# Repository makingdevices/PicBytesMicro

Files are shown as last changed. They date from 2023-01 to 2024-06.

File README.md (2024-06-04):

<!-- Improved compatibility of back to top link: See: https://github.com/othneildrew/Best-README-Template/pull/73 -->

<!--
*** Thanks for checking out the Best-README-Template. If you have a suggestion
*** that would make this better, please fork the repo and create a pull request
*** or simply open an issue with the tag "enhancement".
*** Don't forget to give the project a star!
*** Thanks again! Now go create something AMAZING! :D
-->

<!-- PROJECT SHIELDS -->
<!--
*** I'm using markdown "reference style" links for readability.
*** Reference links are enclosed in brackets [ ] instead of parentheses ( ).
*** See the bottom of this document for the declaration of the reference variables
*** for contributors-url, forks-url, etc. This is an optional, concise syntax you may use.
*** https://www.markdownguide.org/basic-syntax/#reference-style-links
-->
[][ig-url]
[][sponsor-url]
[][stars-url]
[][issues-url]
[][linkedin-url]

<!-- PROJECT LOGO -->
<br />
<div align="center">
  <a href="https://makingdevices.com/links/">
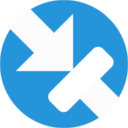
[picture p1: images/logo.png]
    
  </a>

<h3 align="center">Making Devices</h3>

  <p align="center">
    Open Source projects where we struggle with engineering, electronics, coding and who knows what else... Pic Bytes Micro is a 8-bit console based in the PIC18F4550 with an analog LED matrix as the screen.
  </p>
</div>

<!-- TABLE OF CONTENTS -->
<details>
  <summary>Table of Contents</summary>
  <ol>
    <li>
      <a href="#about-the-project">About The Project</a>
      <ul>
        <li><a href="#built-with">Built With</a></li>
      </ul>
    </li>
    <li>
      <a href="#Build-one">Build one</a>
      <ul>
      </ul>
    </li>
    <li><a href="#usage">Usage</a></li>
    <li><a href="#roadmap">Roadmap</a></li>
    <li><a href="#license">License</a></li>
    <li><a href="#contact">Contact</a></li>
    <li><a href="#Sponsor">Sponsor</a></li>
  </ol>
</details>

<!-- ABOUT THE PROJECT -->
## About The Project

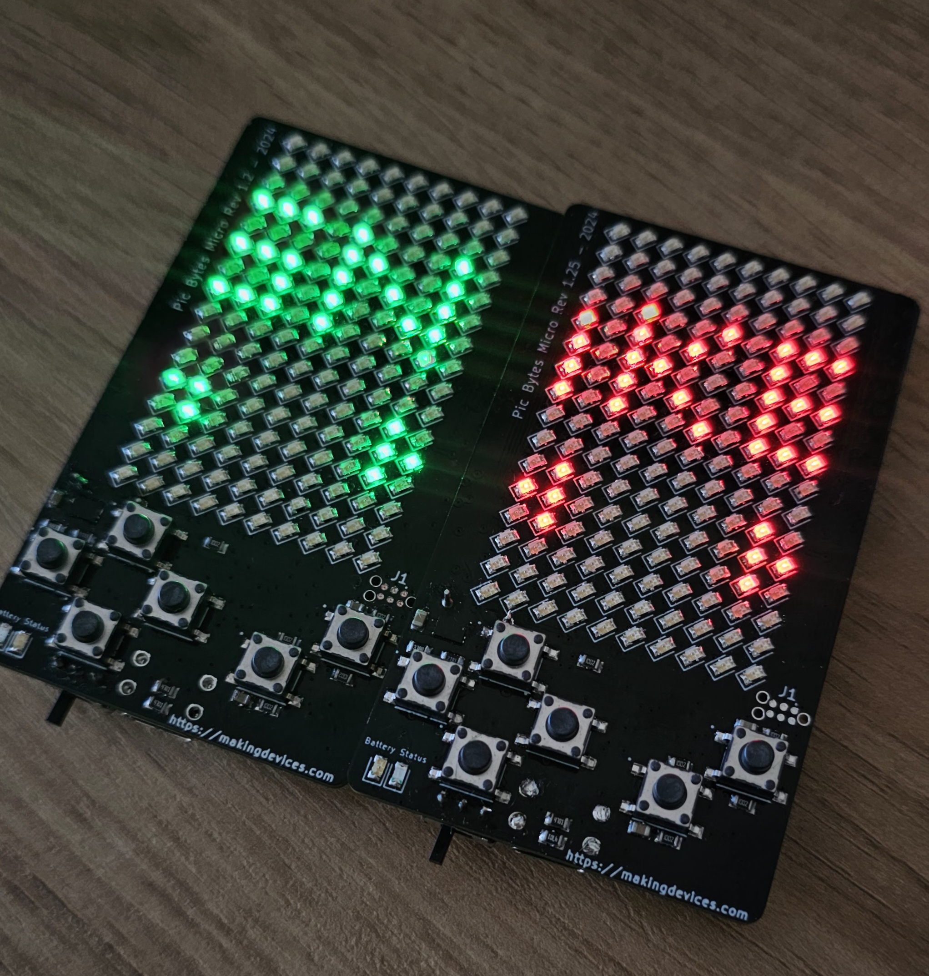
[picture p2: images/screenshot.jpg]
Bytes Counter Shot
[](https://makingdevices.com/PicBytesMicro)

Pic Bytes Micro was born to explore the capabilities of C language inside the PIC18F4550, as I wanted to test if the 8bit microcontroller was able to run some old games such tetris, snake or arkanoid. To maintain the old-fashion look of the project, the screen is made by 16x10 matrix of LEDs, controlled by individual transistors and the IO pins of the PIC. In addition, sounds and a rechargable battery will be added to the device.

<p align="right">(<a href="#readme-top">back to top</a>)</p>

### Built With

[][PIC-url]
[][MPLAB-C-url]
[][kicad-url]
[][sponsor-url-wurth]
[][sponsor-url]

<p align="right">(<a href="#readme-top">back to top</a>)</p>

<!-- GETTING STARTED -->

## Build one
The project is finished and no further development will be made. The device is safe, stable and It was tested. 

1. Get the gerber files for the latest version: [V1.25](/Gerber/PicBytesMicroV1.25.zip) 
2. Send them to a PCB manufacturer ([Our Sponsor is PCBWAY][sponsor-url])
3. You can read the [schematics](/output_files/PicBytesMicro_schematic_V1.25.pdf) 
4. [The firmware is available on the repo](/Simulation%26Firmware) 
5. For most of the components, you can reach to [Würth Elektronik, our sponsor for electronic components](https://www.we-online.com/en) 

<p align="right">(<a href="#readme-top">back to top</a>)</p>

<!-- USAGE EXAMPLES -->
## Usage

Instructions of use:

- When turn on, a menu is shown to select between the available games.
- Once you have played a game, a score board will appear everytime you open the game.
- You have a setting menu to turn-off the init splash and the sound.
- If you leave the console one minute without touching the buttons, it will turn into sleep mode.
- Enjoy!

<p align="right">(<a href="#readme-top">back to top</a>)</p>

<!-- ROADMAP -->
## Roadmap

- [x] Solder the prototype
- [x] Test the LCD of the prototype
- [x] Design a PCB
  - [x] Add rechargeable battery
  - [x] Add USB communication if possible.
  - [x] Add sound control with the buzzers
  - [x] Develop Snake game
  - [x] Develop Tetris game
  - [x] Develop Arkanoid game
  - [x] Score board
  - [x] Sleep Mode
- [x] Validate the design

See the [open issues](https://github.com/makingdevices/PicBytesMicro/issues) for a full list of proposed features (and known issues).

State: Project <b>FINISHED</b> - 22/05/2024

Priority: <b>Medium</b>

<p align="right">(<a href="#readme-top">back to top</a>)</p>

<!-- LICENSE -->
## License

Distributed under three licenses:
- [Hardware](/License/HW_cern_ohl_s_v2.pdf)
- [Software](/License/SW_GPLv3.0.txt)
- [Documentation](/License/Documentation_CC-BY-SA-4.0.txt)

OSHWA License: [ES000047](https://certification.oshwa.org/es000047.html)

[GPL v3 License][license-url] 
<p align="right">(<a href="#readme-top">back to top</a>)</p>

<!-- CONTACT -->
## Contact

Making Devices - [@MakingDevices](https://www.instagram.com/makingdevices/)

Project Link: [https://github.com/makingdevices/PicBytesMicro](https://github.com/makingdevices/PicBytesMicro/)

Other Links: [LinkTree](https://makingdevices.com/links/)

<!-- Sponsor -->
## Sponsors - Würth Elektronik

[Wurth Elektronik](https://www.we-online.com/en) is one of the leading manufacturers of electronic and electromechanical components. The best I can say about them is to show you some pictures: All the LEDs from the board are from them. They also have buttons, resistors and capacitors that we use in all our PCBs. They also have some design kits with a lifetime refill which are amazing for makers and business so you can prototype on the go with a huge variety of components!

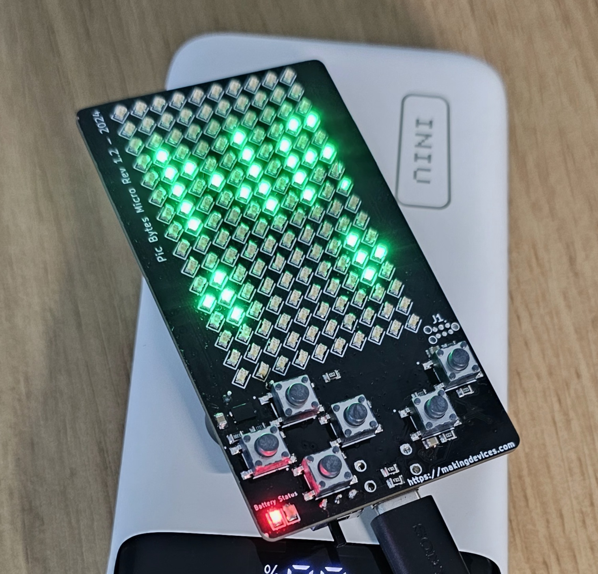
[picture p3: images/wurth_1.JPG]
[][sponsor-url-wurth]
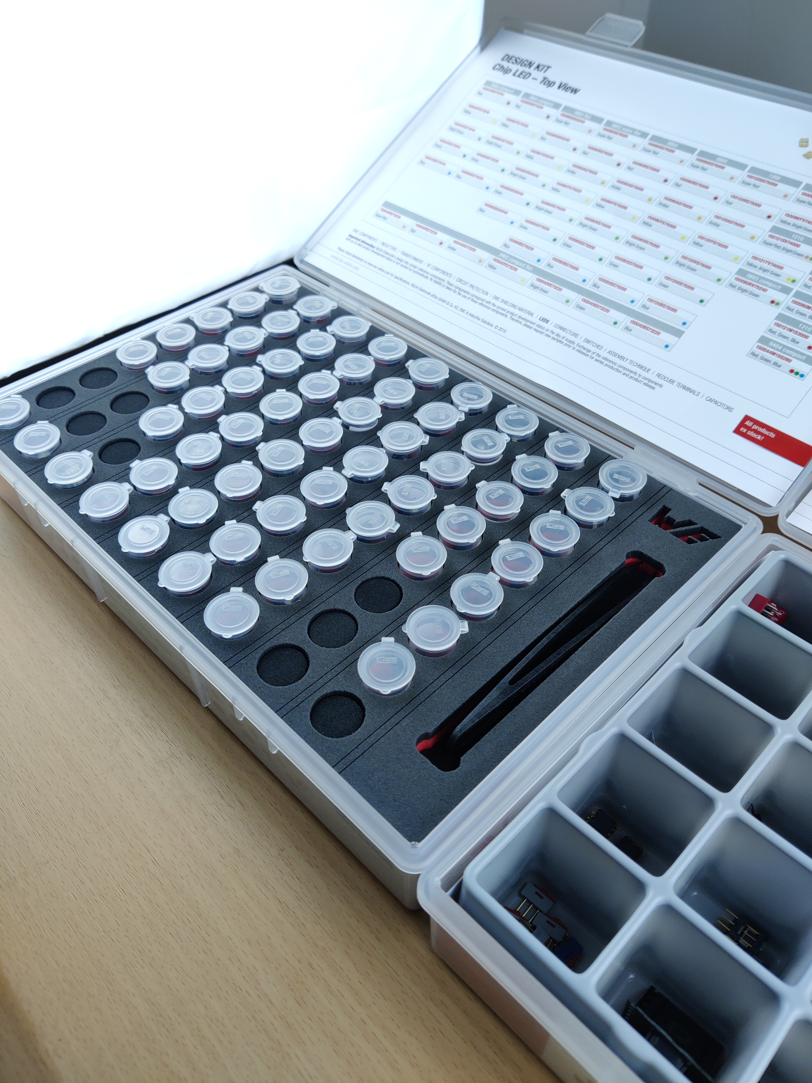
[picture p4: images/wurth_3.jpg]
[][sponsor-url-wurth]

## PCBWAY

[PCBWAY](https://www.pcbway.com/?from=makingdevices) is the most professional PCB manufacturer for prototyping and low-volume production to work with in the world. With more than a decade in the field, They are committed to meeting the needs of their customers from different industries in terms of quality, delivery, cost-effectiveness and any other demanding requests. As Sponsor of Making Devices, they will be in charge of all the PCBs for MDV, allowing both of us to grow together in a long term partnership. We hope you take them into account for your both personal and professional prototypes or products.

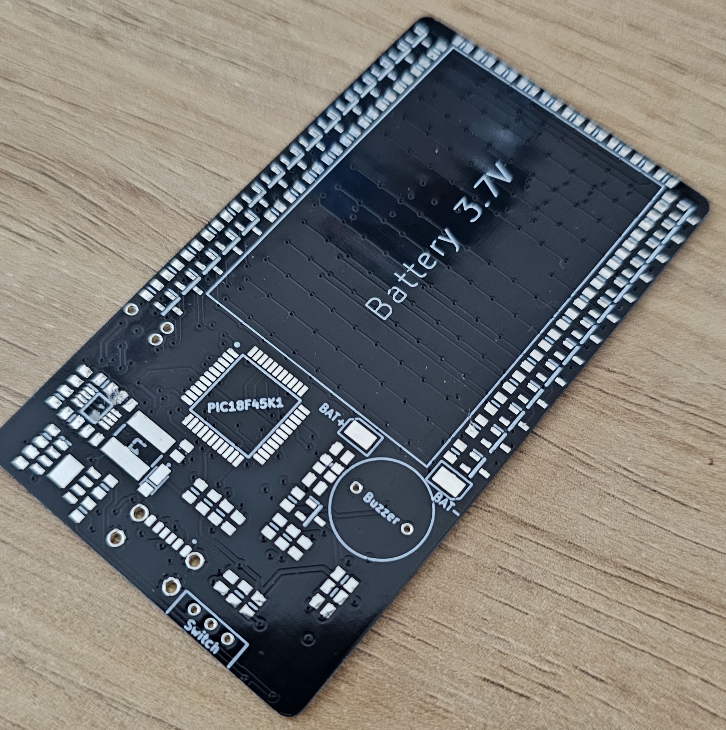
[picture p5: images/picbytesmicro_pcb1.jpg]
[][sponsor-url]
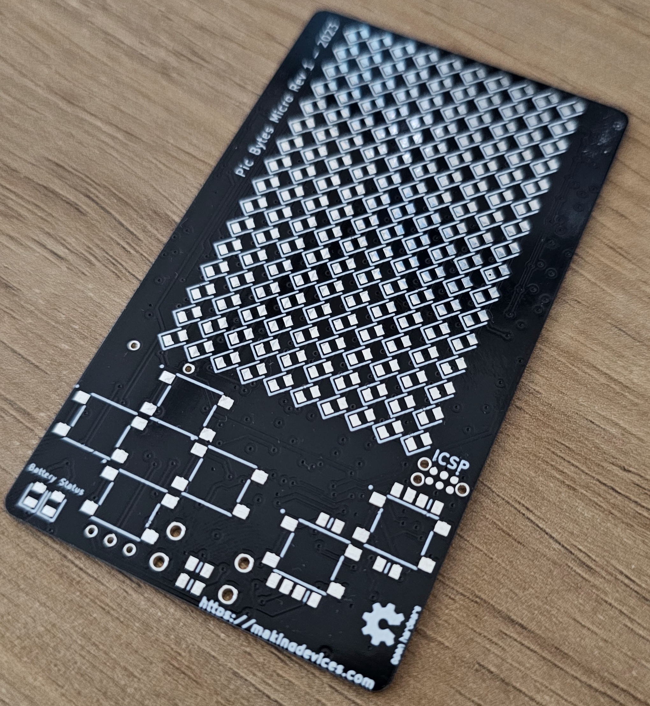
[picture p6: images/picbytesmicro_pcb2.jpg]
[][sponsor-url]

<p align="right">(<a href="#readme-top">back to top</a>)</p>

<!-- MARKDOWN LINKS & IMAGES -->
<!-- https://www.markdownguide.org/basic-syntax/#reference-style-links -->
[contributors-shield]: https://img.shields.io/github/contributors/makingdevices/PicBytesMicro.svg?style=for-the-badge
[contributors-url]: https://github.com/makingdevices/PicBytesMicro/graphs/contributors
[forks-shield]: https://img.shields.io/github/forks/makingdevices/PicBytesMicro.svg?style=for-the-badge
[forks-url]: https://github.com/makingdevices/PicBytesMicro/network/members
[stars-shield]: https://img.shields.io/github/stars/makingdevices/PicBytesMicro.svg?style=for-the-badge
[stars-url]: https://github.com/makingdevices/PicBytesMicro/stargazers
[issues-shield]: https://img.shields.io/github/issues/makingdevices/PicBytesMicro.svg?style=for-the-badge
[issues-url]: https://github.com/makingdevices/PicBytesMicro/issues
[license-shield]: /images/license.png
[license-url]: https://github.com/makingdevices/PicBytesMicro/tree/main/License
[linkedin-shield]: https://img.shields.io/badge/-LinkedIn-black.svg?style=for-the-badge&logo=linkedin&colorB=555
[linkedin-url]: https://www.linkedin.com/company/making-devices/
[sponsor-shield]: https://img.shields.io/badge/SPONSOR-PCBWAY-black.svg?style=for-the-badge&colorB=1200
[sponsor-url]: https://www.pcbway.com/?from=makingdevices
[sponsor-screenshot]: /images/PCB_sponsor.png
[sponsor-pcb-1]: /images/picbytesmicro_pcb1.jpg
[sponsor-pcb-2]: /images/picbytesmicro_pcb2.jpg
[sponsor-wurth-1]: /images/wurth_1.JPG
[sponsor-wurth-3]: /images/wurth_3.jpg
[sponsor-url-wurth]: https://www.we-online.com/en
[product-screenshot]: images/screenshot.jpg
[PIC]: https://img.shields.io/badge/PIC18LF4550-000000?style=for-the-badge
[PIC-url]: https://ww1.microchip.com/downloads/aemDocuments/documents/OTH/ProductDocuments/DataSheets/39632e.pdf
[kicad-shield]: https://img.shields.io/badge/kicad-0b03fc?style=for-the-badge&logo=kicad&logoColor=white
[kicad-url]: https://www.kicad.org/
[YT-screenshot]: images/YT_assembly.PNG
[sponsor-icon]:  https://img.shields.io/badge/-PCBWAY-black.svg?style=for-the-badge&colorB=1200
[ig-shield]: https://img.shields.io/badge/instagram-a83297?style=for-the-badge&logo=instagram&logoColor=white
[ig-url]: https://www.instagram.com/makingdevices/
[MPLAB-C]: https://img.shields.io/badge/MPLAB%20C18-DD0031?style=for-the-badge&logo=C&logoColor=white
[wurth-icon]: https://img.shields.io/badge/Wurth%20elektronik-FF0031?style=for-the-badge&logoColor=white
[MPLAB-C-url]: https://www.microchip.com/en-us/development-tool/SW006011
[Svelte.dev]: https://img.shields.io/badge/Svelte-4A4A55?style=for-the-badge&logo=svelte&logoColor=FF3E00
[Svelte-url]: https://svelte.dev/
[Laravel.com]: https://img.shields.io/badge/Laravel-FF2D20?style=for-the-badge&logo=laravel&logoColor=white
[Laravel-url]: https://laravel.com
[Bootstrap.com]: https://img.shields.io/badge/Bootstrap-563D7C?style=for-the-badge&logo=bootstrap&logoColor=white
[Bootstrap-url]: https://getbootstrap.com
[JQuery.com]: https://img.shields.io/badge/jQuery-0769AD?style=for-the-badge&logo=jquery&logoColor=white
[JQuery-url]: https://jquery.com

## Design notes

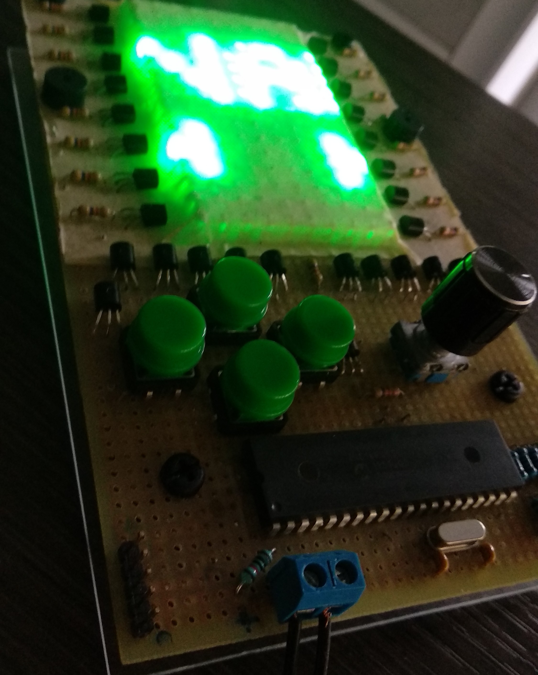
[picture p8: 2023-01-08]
images/screenshot_2.jpg

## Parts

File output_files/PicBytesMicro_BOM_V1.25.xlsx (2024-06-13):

Part | Package | Info | Qty. | Unit Price | Ext. Price | Mouser Ref or first option | Alternative
TP4056 | ESOP8 | Charging IC | 1 | $2.4900 | $2.4900 | - | https://www.lcsc.com/product-detail/Battery-Management-ICs_TECH-PUBLIC-TP4056_C5311018.html
TPS61085 | VSSOP-8 | Step-up 2A | 1 | $2.0700 | $2.0700 | 595-TPS61085TDGKR
AP9214L | U-DFN2535-6 | Battery Prot. IC | 1 | $0.8400 | $0.8400 | 621-AP9214L-AN-HSBR7
FSV360FP | SOD-123-2 | Schottky diode | 1 | $0.4460 | $0.4460 | 512-FSV360FP | 755-RB051M-2YTR
USB Type C | SMT | Power Only | 1 | $0.1631 | $0.1631 | https://www.lcsc.com/product-detail/USB-Connectors_Korean-Hroparts-Elec-TYPE-C-31-M-17_C283540.html | https://www.we-online.com/en/components/products/WR_COM_USB_POWER_DELIVERY_TYPE_C_RECEPTACLE_HORIZONTAL_SMT
4.7uH L | SMD / 6mmX6mm | Inductance | 1 | $0.2980 | $0.2980 | SRN6045-4R7Y
Toggle Switch | TH | Slider | 1 | $0.1286 | $0.1286 | https://www.lcsc.com/product-detail/Slide-Switches_Korean-Hroparts-Elec-K3-1260D-L1_C92657.html | https://www.we-online.com/en/components/products/SLTU_10X2_5_THT_RIGHT_ANGLED?sq=450302014072
Buttons | SMD / 6mmx6mm | Buttons | 6 | $0.4500 | $2.7000 | Wurth: Order Code: 430182050816
LED Green | smd 0805 | Power indicator | 1 | $0.1400 | $0.1400 | Wurth: Order Code: 150080GS75000
LED Red | smd 0805 | Charge indicator | 1 | $0.1400 | $0.1400 | Wurth: Order Code: 150080RS75000
LED screen | smd 0805 | Any color | 160 | $0.1400 | $22.4000 | Wurth: Order Code: 150080RS75000
Y - 12MHz | smd 2.5 x 2.0mm - 4p | Quartz Crystal | 1 | $1.1000 | $1.1000 | 8Z-12.000MAAJ-T
PIC18F4550-I/PT | TQFP-44 | Microcontroller | 1 | $6.6000 | $6.6000 | 579-PIC18F4550-I/PT
Buzzer | TH - 12mm Diameter | Buzzer | 1 | $0.9190 | $0.9190 | 490-CMI-1295-0585T
Q - NPN Transistor | SOT-23-3 | NPN Transistor - 600mA | 29 | $0.3810 | $11.0490 | 863-SMMBT5551LT1G
Capacitor 1uF | smd 0805 | Any Above 20V. | 1 | $0.0500 | $0.0500
Capacitor 820pF | smd 0805 | Any Above 20V. | 1 | $0.3060 | $0.3060 | 581-08055A821K
Capacitor 22uF | smd 0805 | Any Above 20V. | 1 | $0.2450 | $0.2450 | 963-JMK212BBJ226MG8T
Capacitor 100nF | smd 0805 | Any Above 20V. | 7 | $0.0500 | $0.3500
Capacitor 47uF | smd 0805 | Any Above 20V. | 1 | $1.0900 | $1.0900 | 581-0805ZD476MAT2A
Capacitor 10uF | smd 0805 | Any Above 20V. | 1 | $0.0500 | $0.0500
Capacitor 22pF | smd 0805 | Any Above 20V. | 2 | $0.0500 | $0.1000
Resistor 220 | smd 0806 | 1/4 W or higher | 10 | $0.0500 | $0.5000
Resistor 330 | smd 0807 | 1/4 W or higher | 1 | $0.2280 | $0.2280 | 652-CMP0805AFX-3300L
Resistor 1k | smd 0808 | 1/4 W or higher | 2 | $0.0500 | $0.1000
Resistor 2k | smd 0809 | 1/4 W or higher | 1 | $0.0500 | $0.0500
Resistor 2.7k | smd 0810 | 1/4 W or higher | 1 | $0.1310 | $0.1310 | 71-CRCW0805-2.7K
Resistor 4.7k | smd 0811 | 1/4 W or higher | 29 | $0.0500 | $1.4500
Resistor 5.1k | smd 0812 | 1/4 W or higher | 2 | $0.0500 | $0.1000
Resistor 10k | smd 0813 | 1/4 W or higher | 14 | $0.0500 | $0.7000
Resistor 27k | smd 0814 | 1/4 W or higher | 1 | $0.1050 | $0.1050 | 603-RT0805FRE1327KL
Resistor 44.2k | smd 0815 | 1/4 W or higher | 1 | $0.1580 | $0.1580 | 71-CRCW0805-44.2K-E3
Resistor 82k | smd 0816 | 1/4 W or higher | 1 | $0.0880 | $0.0880 | 603-RC0805FR-0782KL
battery Li-ion 3.7V | 35mm x 51mm max | Wires will be soldered to PCB | 1 | $10.9500 | $10.9500 | https://www.digikey.com/en/products/detail/sparkfun-electronics/PRT-18286/14302550
 |  |  |  | Total: | $68.2347
Otros:
Cable TC2030 para programar microchip
PICKIT 3 para programar el micro

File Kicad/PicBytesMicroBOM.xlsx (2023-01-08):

Part | Info | Qty. | Unit Price | Ext. Price | LSCS | Link
PIC18F45K50-I/PT | MicroProcessor | 1 | $4.0300 | $4.0300 | C219580 | https://lcsc.com/product-detail/Others_Microchip-Tech_PIC18F45K50-I-PT_Microchip-Tech-PIC18F45K50-I-PT_C219580.html
TJ-S2012SW8TGLC2G-A5 | Green LED | 160 | $0.0291 | $4.6600 | C192319 | https://lcsc.com/product-detail/Others_TOGIALED-TJ-S2012SW8TGLC2G-A5_C192319.html
MMBT5551LT1G | NPN 600mA | 30 | $0.0155 | $0.4659 | C41095 | https://lcsc.com/product-detail/Transistors-NPN-PNP_ON-Semiconductor-MMBT5551LT1G_C41095.html
RTT052200FTP | 220 Ohm 0805 | 10 | $0.0024 | $0.0243 | C104105 | https://lcsc.com/product-detail/Chip-Resistor-Surface-Mount_220R-2200-1_C104105.html
RTT054701FTP | 4.7k Ohm 0805 | 28 | $0.0042 | $0.1164 | C104344 | https://lcsc.com/product-detail/Chip-Resistor-Surface-Mount_4-7KR-4701-1_C104344.html
TMB12A05 | Buzzer 5V | 2 | $0.1893 | $0.3786 | C96093 | https://lcsc.com/product-detail/Buzzers_Jiangsu-Huaneng-Elec-TMB12A05_C96093.html
CC0805JRNPOCBN220 | 22pF 0805 | 2 | $0.0386 | $0.0772 | C113840 | https://lcsc.com/product-detail/Multilayer-Ceramic-Capacitors-MLCC-SMD-SMT_YAGEO-CC0805JRNPOCBN220_C113840.html
0805W8F1002T5E | 10K 0805 | 1 | $0.0028 | $0.0028 | C38522 | https://lcsc.com/product-detail/Chip-Resistor-Surface-Mount_UNI-ROYAL-Uniroyal-Elec-0805W8F1002T5E_C38522.html
0805B474K500CT | 470nF | 1 | $0.0210 | $0.0210 | C335536 | https://lcsc.com/product-detail/Multilayer-Ceramic-Capacitors-MLCC-SMD-SMT_Walsin-Tech-Corp-0805B474K500CT_C335536.html
SS34 | Schottky Diode | 1 | $0.0273 | $0.0273 | C8678 | https://lcsc.com/product-detail/Schottky-Barrier-Diodes-SBD_MDD_SS34_SS34_C8678.html
SMRH74-220MT | 22uF Inductor | 1 | $0.1731 | $0.1731 | C27442 | https://lcsc.com/product-detail/Power-Inductors_ReliaPro_SMRH74-220MT_22uH_C27442.html
Battery Protector | FS312F-G | 1 | $0.1152 | $0.1152 | C82736 | https://lcsc.com/product-detail/Battery-Protection-ICs_FORTUNE_FS312F-G_FS312F-G_C82736.html
MT3608 | Step-Up Vdc | 1 | $0.0875 | $0.0875 | C84817 | https://lcsc.com/product-detail/DC-DC-Converters_AEROSEMI_MT3608_MT3608_C84817.html
TJ-S2012SW8TGLC2R-A5 | Red LED | 1 | $0.0226 | $0.0226 | C192318 | https://lcsc.com/product-detail/Others_TOGIALED-TJ-S2012SW8TGLC2R-A5_C192318.html
TP4056-42-ESOP8 | Bat. Charger IC | 1 | $0.1849 | $0.1849 | C16581 | https://lcsc.com/product-detail/PMIC-Battery-Management_TOPPOWER_TP4056_TP4056_C16581.html
WR08X7501FTL | 7.5K 0805 | 1 | $0.0035 | $0.0035 | C164012 | https://lcsc.com/product-detail/Chip-Resistor-Surface-Mount_Walsin-Tech-Corp-WR08X7501FTL_C164012.html
RTT51000FTP | 100 0805 | 1 | $0.0044 | $0.0044 | C103902 | https://lcsc.com/product-detail/Chip-Resistor-Surface-Mount_100R-1000-1_C103902.html
CR0805-FX-1001ELF | 1k 0805 | 1 | $0.0110 | $0.0110 | C204136 | https://lcsc.com/product-detail/Chip-Resistor-Surface-Mount_BOURNS-CR0805-FX-1001ELF_C204136.html
AECR0805F2K00K9 | 2k 0805 | 1 | $0.0046 | $0.0046 | C328391 | https://lcsc.com/product-detail/Chip-Resistor-Surface-Mount_Resistor-Today-AECR0805F2K00K9_C328391.html
GRM219R61C226ME15L | 22uF Cap | 2 | $0.1694 | $0.3388 | C162295 | https://lcsc.com/product-detail/Others_Murata-Electronics_GRM219R61C226ME15L_Murata-Electronics-GRM219R61C226ME15L_C162295.html
FS8205 | Mosfet IC | 1 | $0.1687 | $0.1687 | C32254 | https://lcsc.com/product-detail/MOSFET_FORTUNE_FS8205_FS8205_C32254.html
K3-1260D-L1 | Toggle Switch | 1 | $0.1428 | $0.1428 | C92657 | https://lcsc.com/product-detail/Toggle-Switches_Korean-Hroparts-Elec-K3-1260D-L1_C92657.html
AC0805KRX7R9BB104 | 0.1uF Cap | 1 | $0.0198 | $0.0198 | C277502 | https://lcsc.com/product-detail/Others_YAGEO-AC0805KRX7R9BB104_C277502.html
CL21A106KAYNNNE | 10uF | 1 | $0.0274 | $0.0274 | C15850 | https://lcsc.com/product-detail/Multilayer-Ceramic-Capacitors-MLCC-SMD-SMT_SAMSUNG_CL21A106KAYNNNE_10uF-106-10-25V_C15850.html
Battery | 3.7V - 1000mAh | 1 | $2.6400 | $2.6400 |  | https://es.aliexpress.com/item/33017241715.html?spm=a2g0s.9042311.0.0.117c63c0AethMC
Korean Hroparts Elec TYPE-C-31-M-17 | USB Type C | 1 | $0.2292 | $0.2292 | C283540 | https://lcsc.com/product-detail/Others_Korean-Hroparts-Elec-TYPE-C-31-M-17_C283540.html
 |  |  |  | Total: | $13.9772

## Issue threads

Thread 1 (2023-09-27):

Assembly Second Iteration

makingdevices, 2023-09-27:
- [x] Receive all the components
- [x] Assembly the second iteration
- [x] Check if the microcontroller can be programmed

makingdevices, 2023-12-15:
New bugs sin version v1.0 discovered

Closed 2023-12-15.

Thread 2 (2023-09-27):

Battery

makingdevices, 2023-09-27:
**Design:**

- [x] Pouch Li-ion battery (1 cell).
- [x] 5.0V power supply for the display and all the electronics.
- [x] 5.0V USB type-C input voltage.
- [x] There are Two lights: 1 for charging and 1 for input voltage.

**Validate:**

- [x] There is a switch to turn on-off the device (disconnects all the power after the battery).
- [x] You can charge the battery while playing.
- [x] You should be able to read the State of Charge of the battery.
- [x] At least 20min lifetime with any game.
- [x] When you plug the device, the light for the input voltage is ON.
- [x] When you are chargind the battery, the battery indicator is ON.

makingdevices, 2024-02-28:
In the v1.2, the battery now has de AP protection IC, so it is quite robust now. The ADC need testing

makingdevices, 2024-03-24:
We are reading the voltage and showing a LOW BAT error when V below 3.25V

Closed 2024-03-24.

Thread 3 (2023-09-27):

Display

makingdevices, 2023-09-27:
- [x] 16x10 LED display. Every pixel is working as expected.
- [x] Power consumption below 0.3A
- [x] Supplied at 5V and can be controlled from the PIC18F

makingdevices, 2024-03-25:
The power consumption of the complete console is about 40mA average
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

Closed 2024-03-25.

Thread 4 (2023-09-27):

Crosspad Buttons

makingdevices, 2023-09-27:
Design:

- [x] There is a cross pad and a button A&B.

Validate:

- [x] There is no bouncing effect on the buttons.
- [x] The buttons are confortable to play with.
- [x] The microcontroller can read the state of the buttons

makingdevices, 2024-02-28:
There is one bug related with the Right button. Everything else is working

makingdevices, 2024-03-18:
I close the Issue with the bug

Closed 2024-03-18.

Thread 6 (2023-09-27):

Sound

makingdevices, 2023-09-27:
The videoconsole should be able to play basic sound notes with the buzzer.

Design:

- [x] The PWM is connected to the buzzer and can be used to control some music tones.

Validate:

- [x] The music works with the games
- [x] It should be a Settings menu for muting the buzzer (or unmute)

makingdevices, 2024-02-28:
The buzzer can be activated. PWM needs to be tested

Closed 2024-03-21.

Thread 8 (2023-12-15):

The pic18F4550 cannot be programmed

makingdevices, 2023-12-15:
The programming port in the PCB is wrong. It should be using the port number one.

The main chip cannot be burned with the firmware

makingdevices, 2023-12-15:
You will find attach the pinout which were used
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

makingdevices, 2024-02-28:
In the HW V1.2 this is fixed and the micro can be programmed without issues

Closed 2024-02-28.

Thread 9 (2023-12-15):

The buttons are wrong connected

makingdevices, 2023-12-15:
The buttons were placed in the wrong direction. They create a short on the input pins so they are always "pressed".

New routing to the PCB should be made.

makingdevices, 2024-02-28:
In the V1.2 the right button is wrong connected (GROUND pin D:). Need to be fixed in a new revision.

makingdevices, 2024-05-16:
V1.25 received and assembled. No short-circuit on the pads. The software still needs to be programmed into the micro to test if everything is OK

makingdevices, 2024-05-21:
Everything seems OK with the buttons in the v1.25

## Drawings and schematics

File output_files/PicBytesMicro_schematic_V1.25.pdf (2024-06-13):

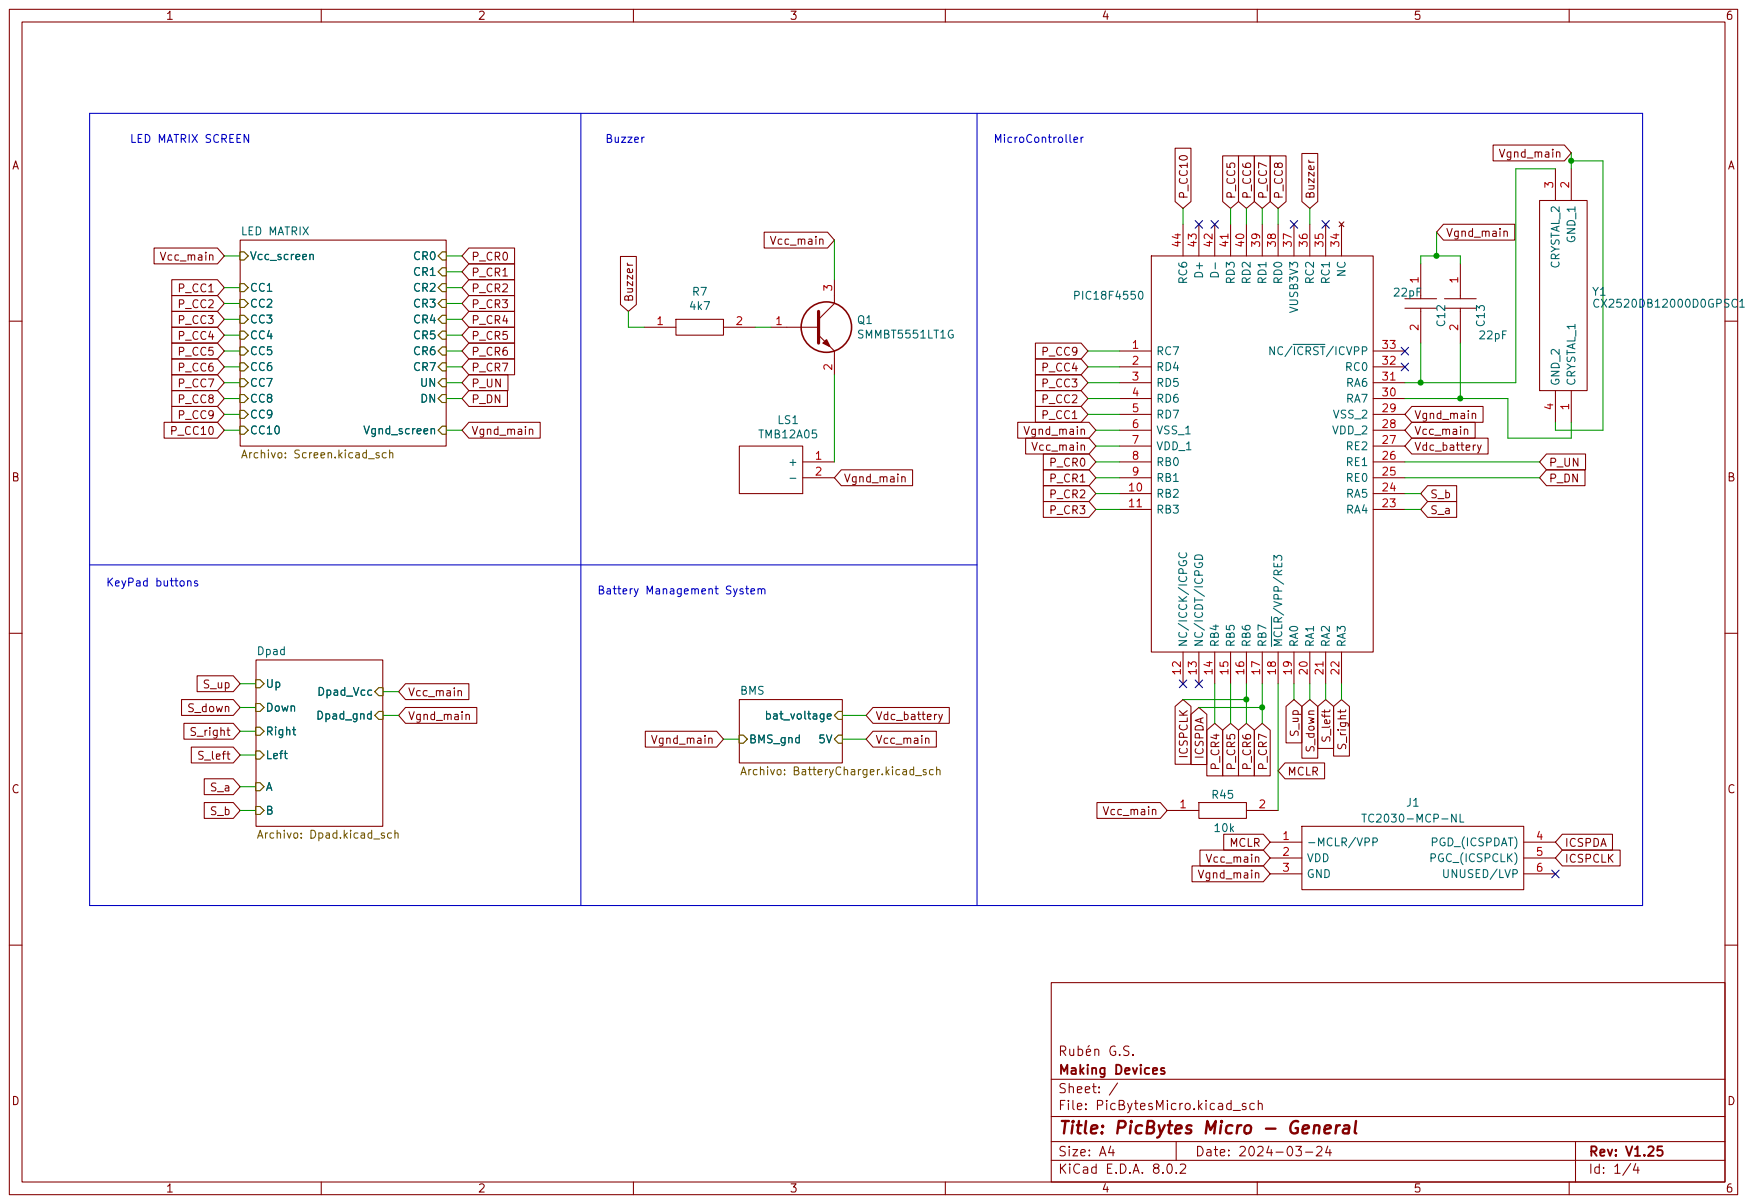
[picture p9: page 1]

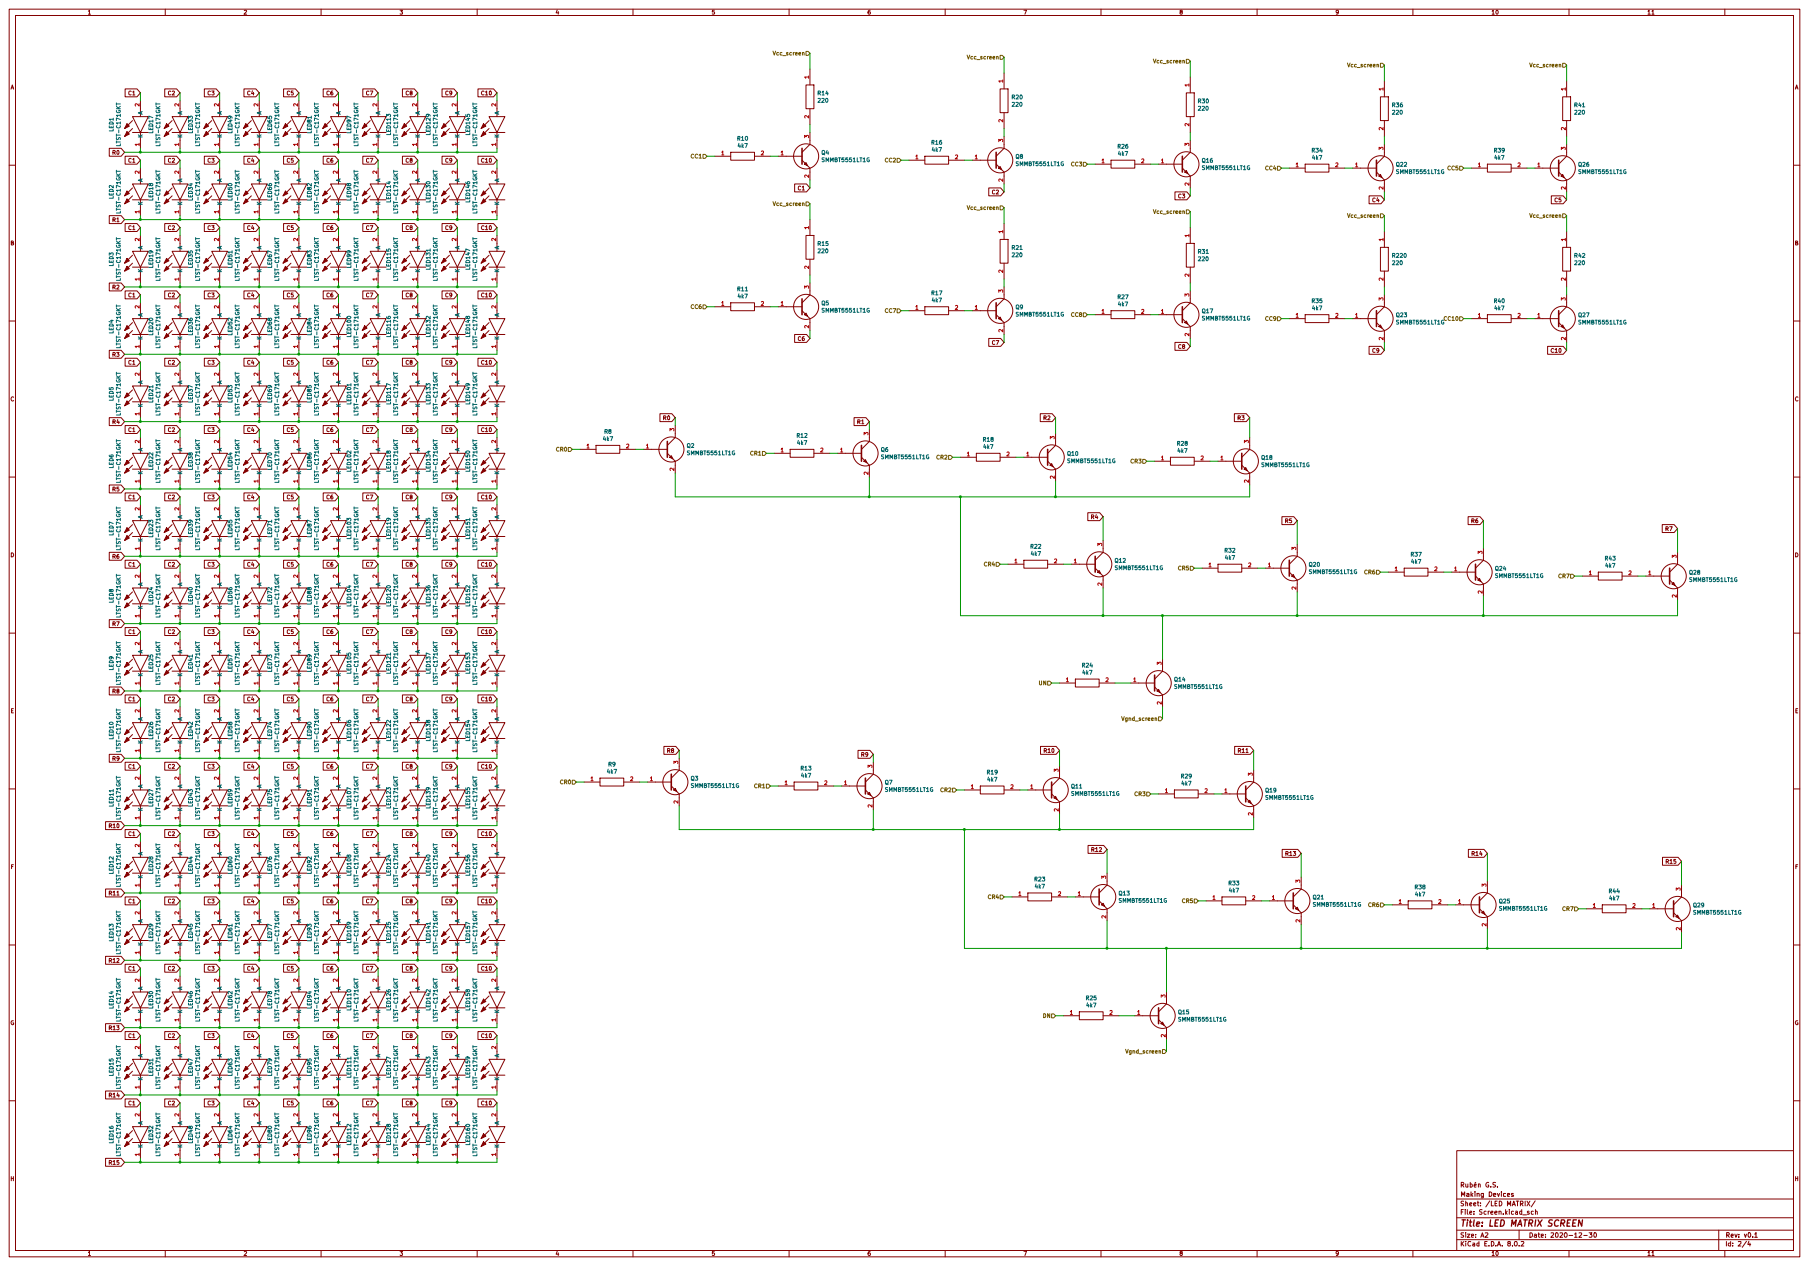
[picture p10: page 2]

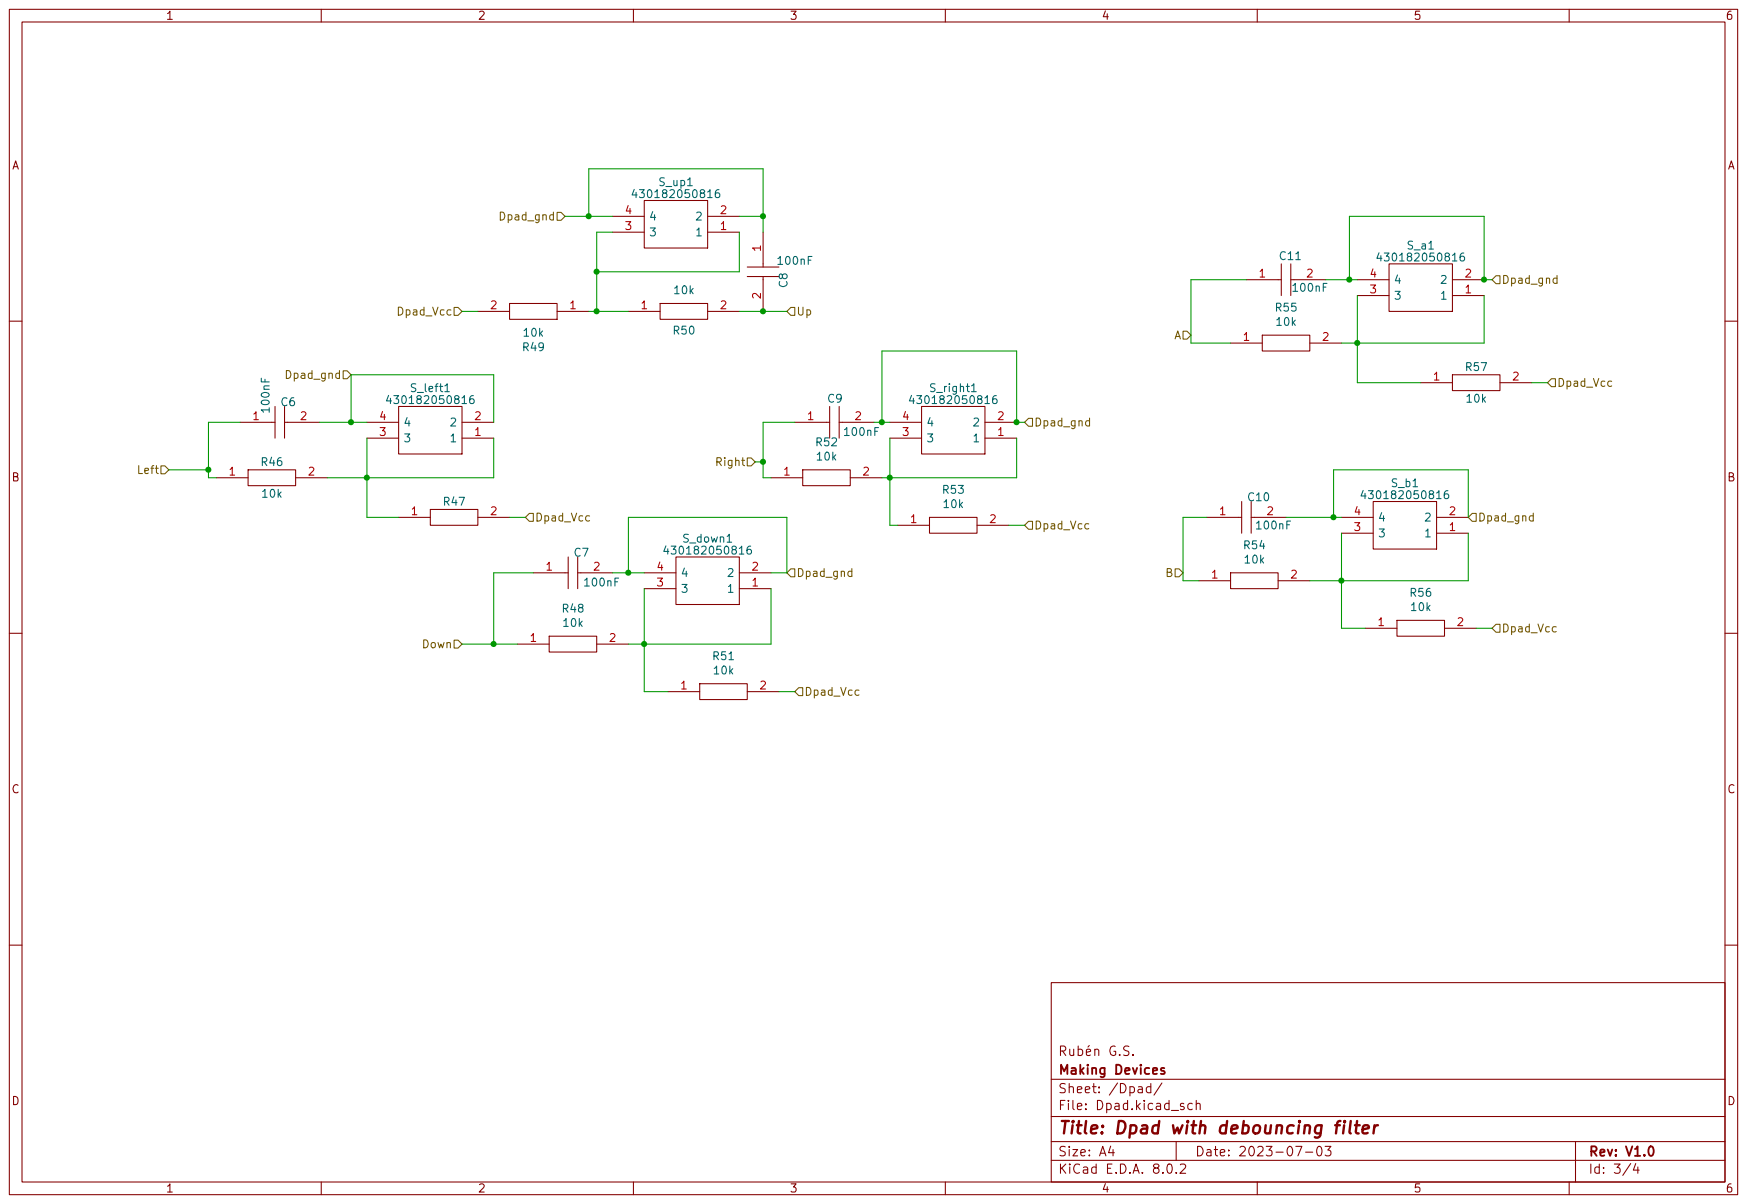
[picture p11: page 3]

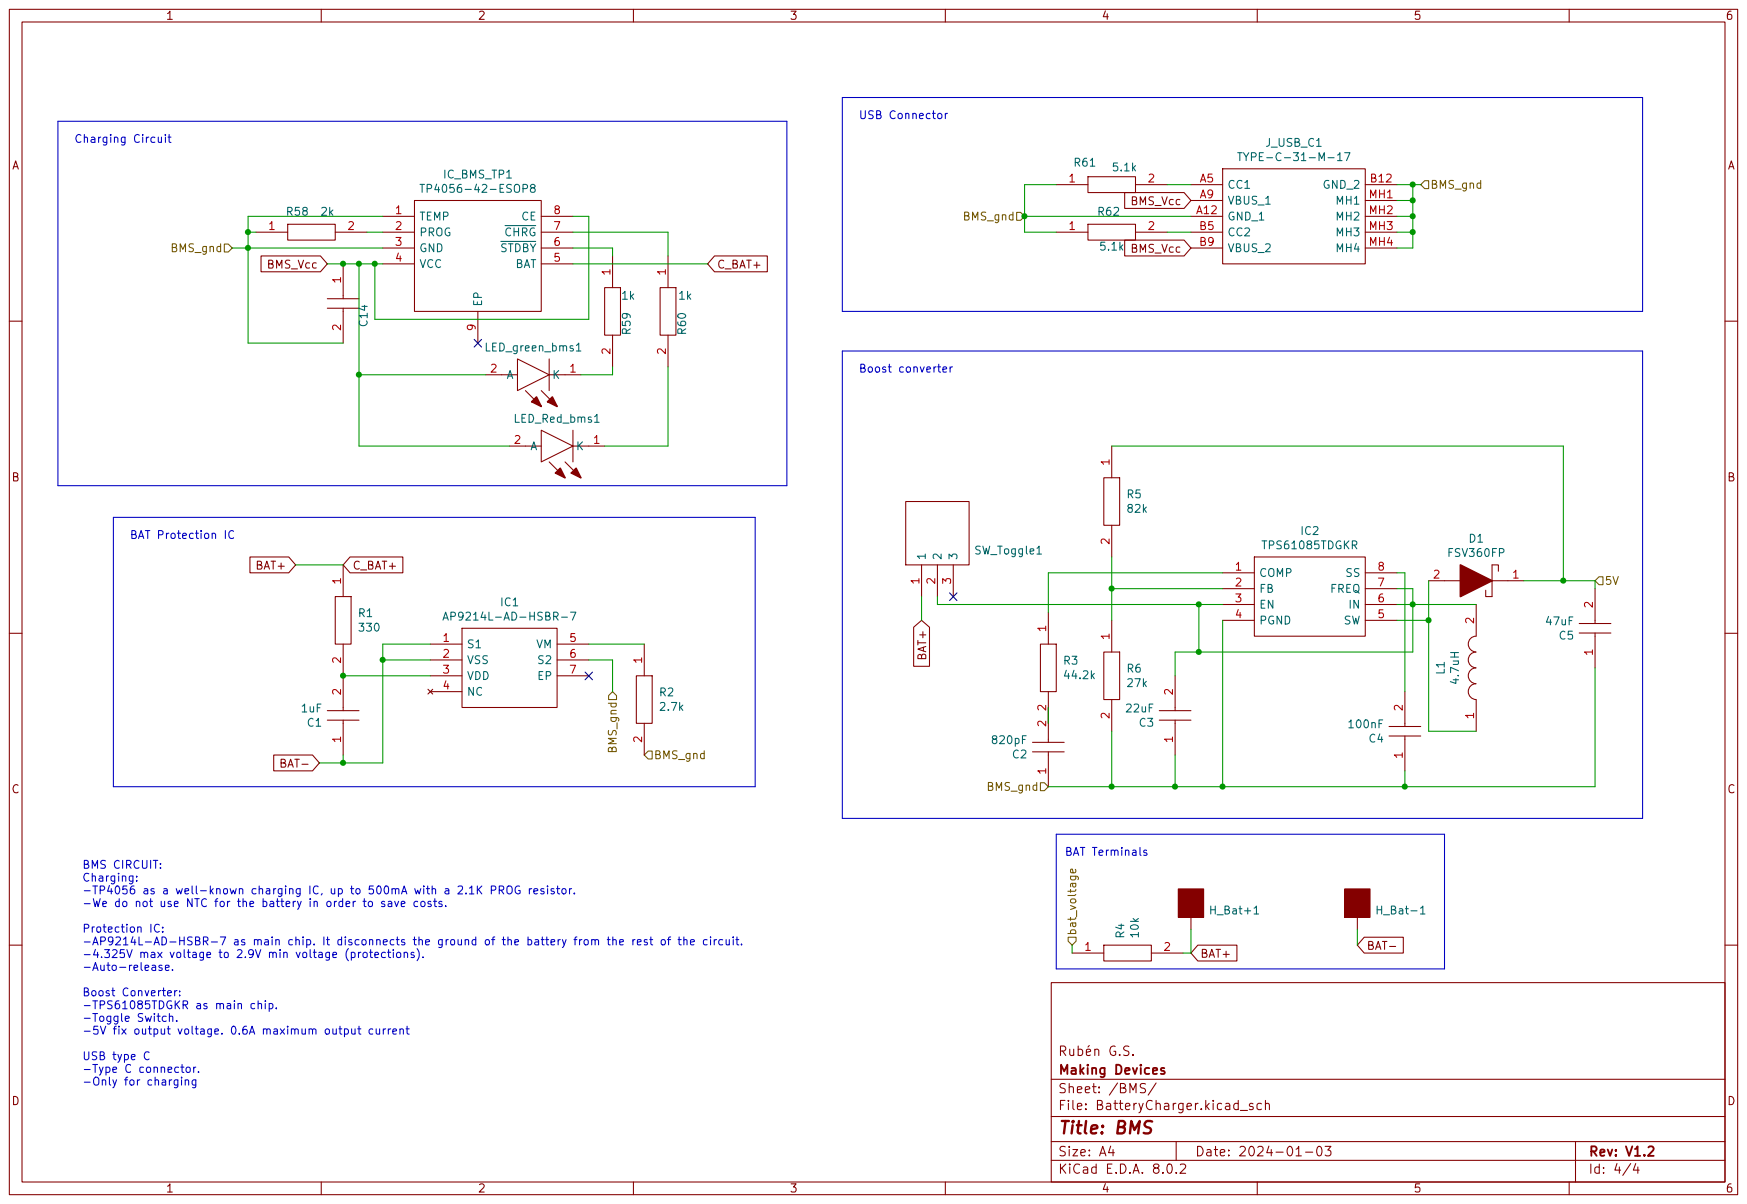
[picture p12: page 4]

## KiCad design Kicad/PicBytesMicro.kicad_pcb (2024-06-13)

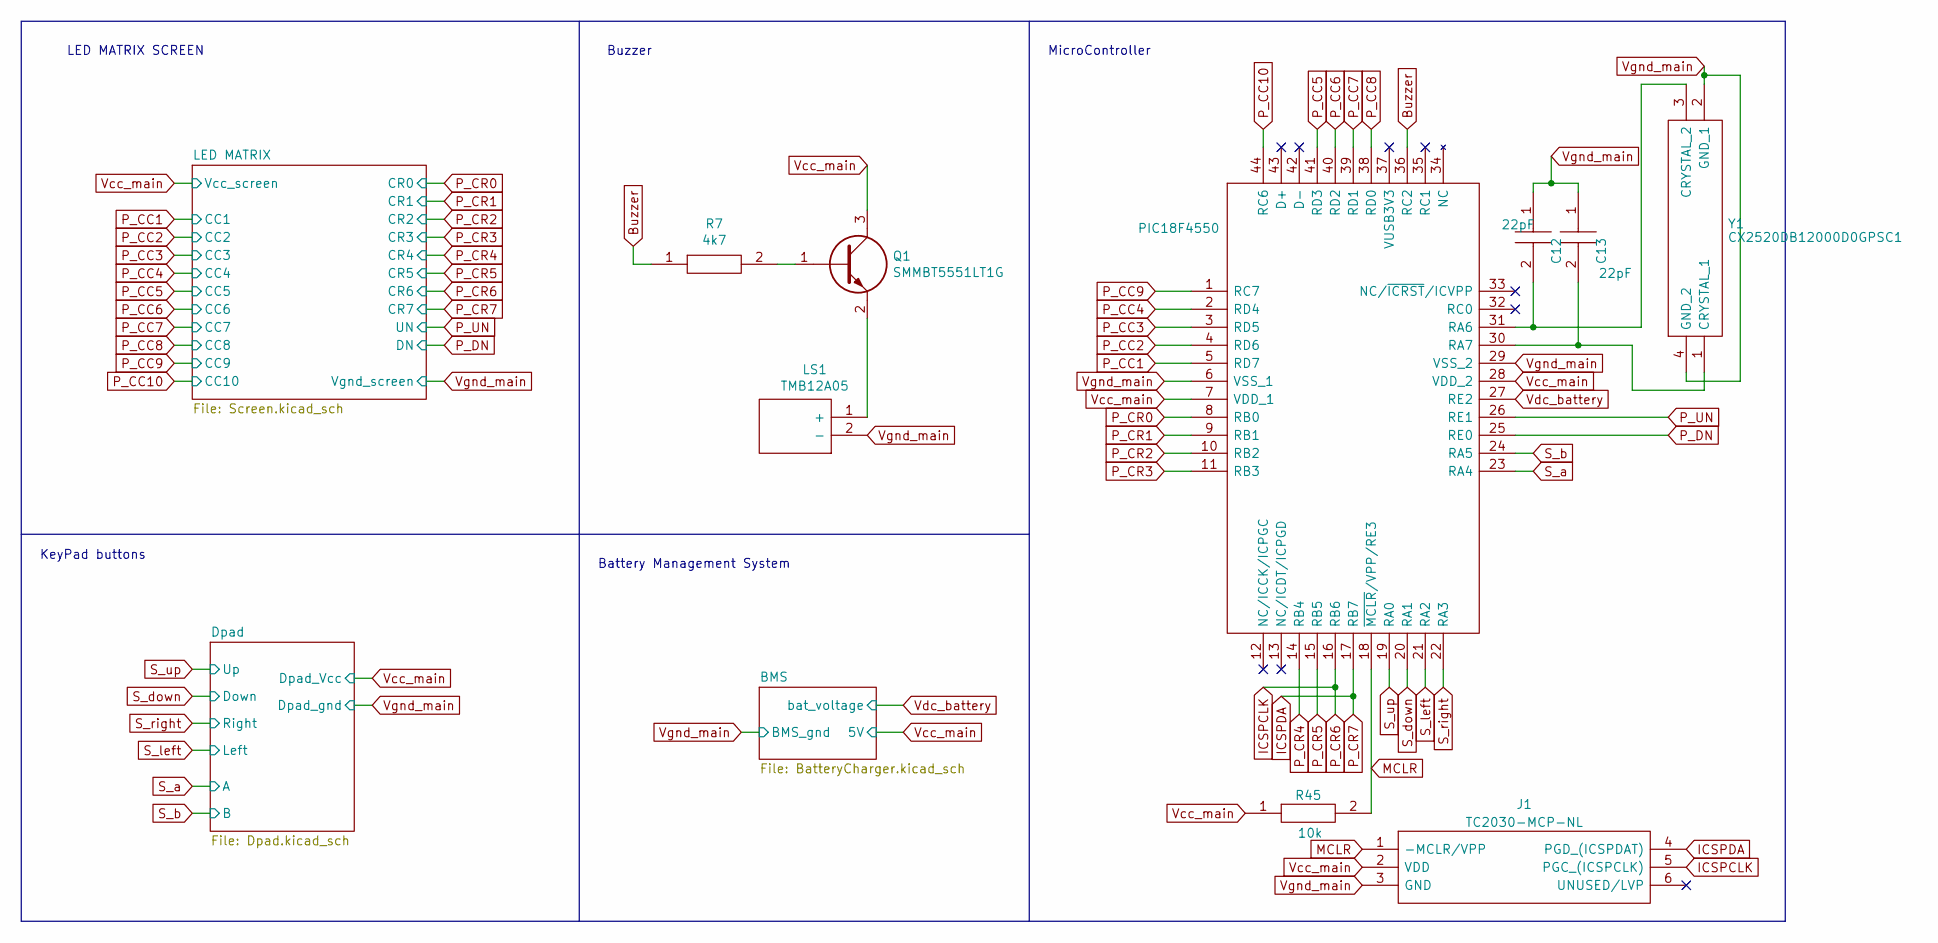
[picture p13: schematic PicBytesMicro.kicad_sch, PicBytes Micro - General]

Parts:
C12, C13: 22pF; CAPC2012X145N; Manufacturer_Part_Number GCG21BR71H154KA01K
J1: TC2030-MCP-NL; Manufacturer_Part_Number TC2030-MCP-NL
LS1: TMB12A05; Manufacturer_Part_Number TMB12A05
PIC18F4550: PIC18F4550-I_PT; QFP80P1200X1200X120-44N; Manufacturer_Part_Number PIC18F45K50-I/PT
Q1: SMMBT5551LT1G; SOT96P237X111-3N; Manufacturer_Part_Number SMMBT5551LT1G
R7: 4k7; RESC2012X65N; Manufacturer_Part_Number KTR10EZPF4220
R45: 10k; RESC2012X65N; Manufacturer_Part_Number KTR10EZPF4220
Y1: CX2520DB12000D0GPSC1; Manufacturer_Part_Number CX2520DB12000D0GPSC1

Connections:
Buzzer: PIC18F4550.36 (RC2), R7.1
ICSPCLK: J1.5 (PGC_(ICSPCLK)), PIC18F4550.16 (RB6); also elsewhere on the board
ICSPDA: J1.4 (PGD_(ICSPDAT)), PIC18F4550.17 (RB7); also elsewhere on the board
MCLR: J1.1 (-MCLR/VPP), PIC18F4550.18 (~MCLR/VPP/RE3), R45.2
unnamed: LS1.1 (+), Q1.2
unnamed: C12.2, PIC18F4550.31 (RA6), Y1.3 (CRYSTAL_2)
unnamed: C13.2, PIC18F4550.30 (RA7), Y1.1 (CRYSTAL_1)
unnamed: Q1.1, R7.2
P_CC1: PIC18F4550.5 (RD7); also elsewhere on the board
P_CC2: PIC18F4550.4 (RD6); also elsewhere on the board
P_CC3: PIC18F4550.3 (RD5); also elsewhere on the board
P_CC4: PIC18F4550.2 (RD4); also elsewhere on the board
P_CC5: PIC18F4550.41 (RD3); also elsewhere on the board
P_CC6: PIC18F4550.40 (RD2); also elsewhere on the board
P_CC7: PIC18F4550.39 (RD1); also elsewhere on the board
P_CC8: PIC18F4550.38 (RD0); also elsewhere on the board
P_CC9: PIC18F4550.1 (RC7); also elsewhere on the board
P_CC10: PIC18F4550.44 (RC6); also elsewhere on the board
P_CR0: PIC18F4550.8 (RB0); also elsewhere on the board
P_CR1: PIC18F4550.9 (RB1); also elsewhere on the board
P_CR2: PIC18F4550.10 (RB2); also elsewhere on the board
P_CR3: PIC18F4550.11 (RB3); also elsewhere on the board
P_CR4: PIC18F4550.14 (RB4); also elsewhere on the board
P_CR5: PIC18F4550.15 (RB5); also elsewhere on the board
P_DN: PIC18F4550.25 (RE0); also elsewhere on the board
P_UN: PIC18F4550.26 (RE1); also elsewhere on the board
S_a: PIC18F4550.23 (RA4); also elsewhere on the board
S_b: PIC18F4550.24 (RA5); also elsewhere on the board
S_down: PIC18F4550.20 (RA1); also elsewhere on the board
S_left: PIC18F4550.21 (RA2); also elsewhere on the board
S_right: PIC18F4550.22 (RA3); also elsewhere on the board
S_up: PIC18F4550.19 (RA0); also elsewhere on the board
Vcc_main: J1.2 (VDD), PIC18F4550.7 (VDD_1), PIC18F4550.28 (VDD_2), Q1.3, R45.1; also elsewhere on the board
Vdc_battery: PIC18F4550.27 (RE2); also elsewhere on the board
Vgnd_main: C12.1, C13.1, J1.3 (GND), LS1.2 (-), PIC18F4550.6 (VSS_1), PIC18F4550.29 (VSS_2), Y1.2 (GND_1), Y1.4 (GND_2); also elsewhere on the board

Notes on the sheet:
MicroController
KeyPad buttons
Battery Management System
LED MATRIX SCREEN
Buzzer

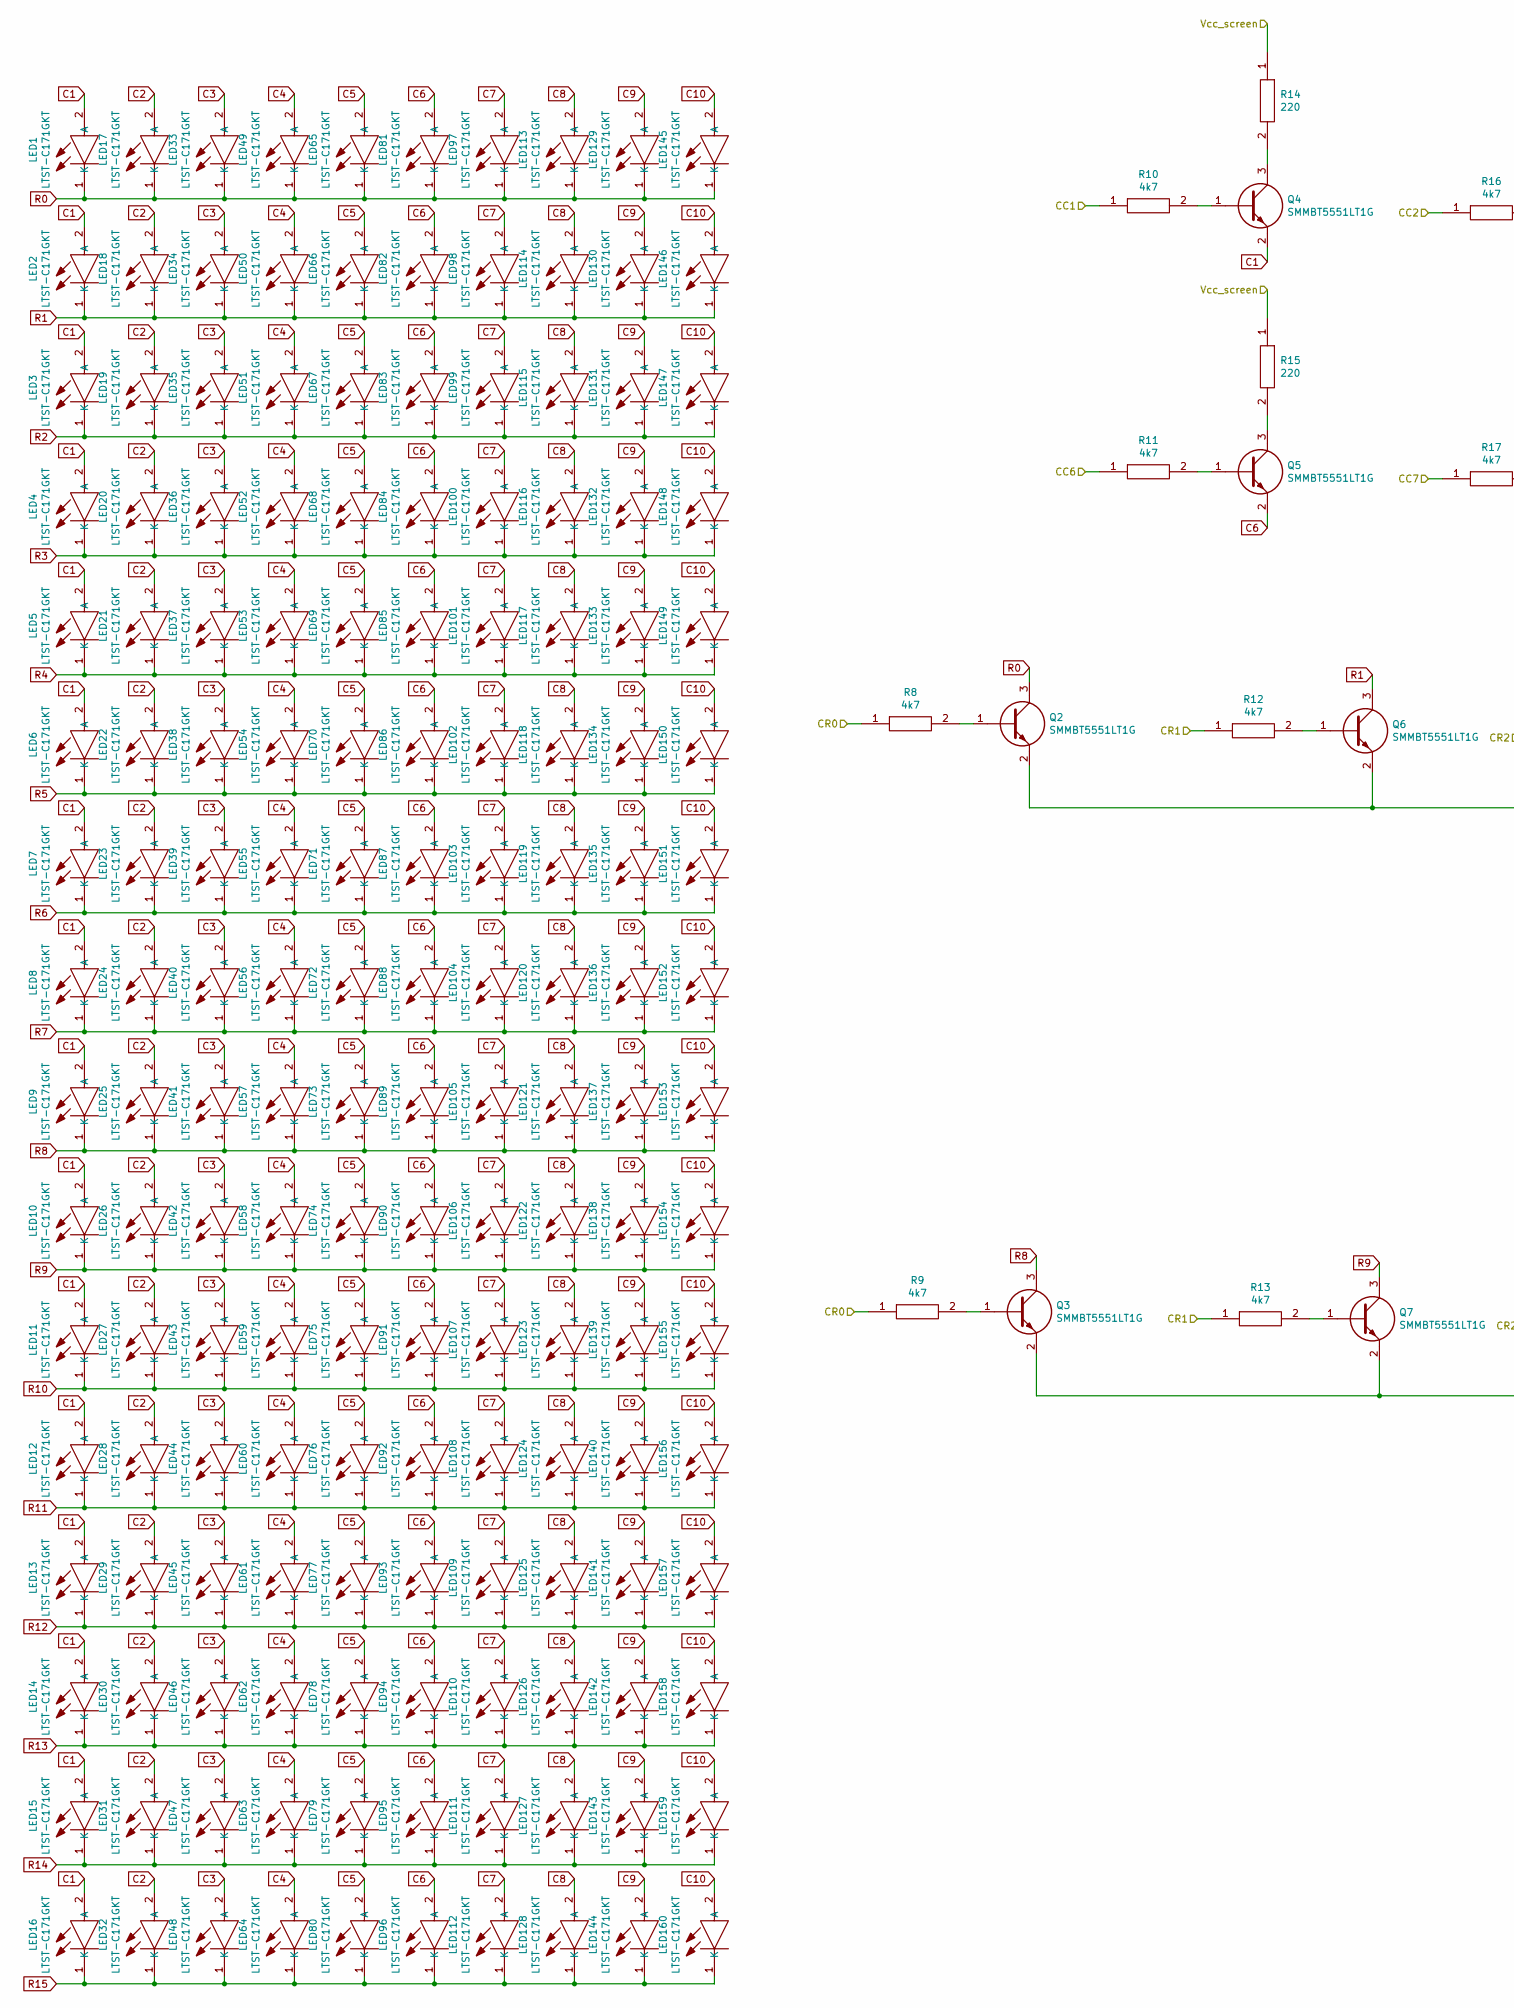
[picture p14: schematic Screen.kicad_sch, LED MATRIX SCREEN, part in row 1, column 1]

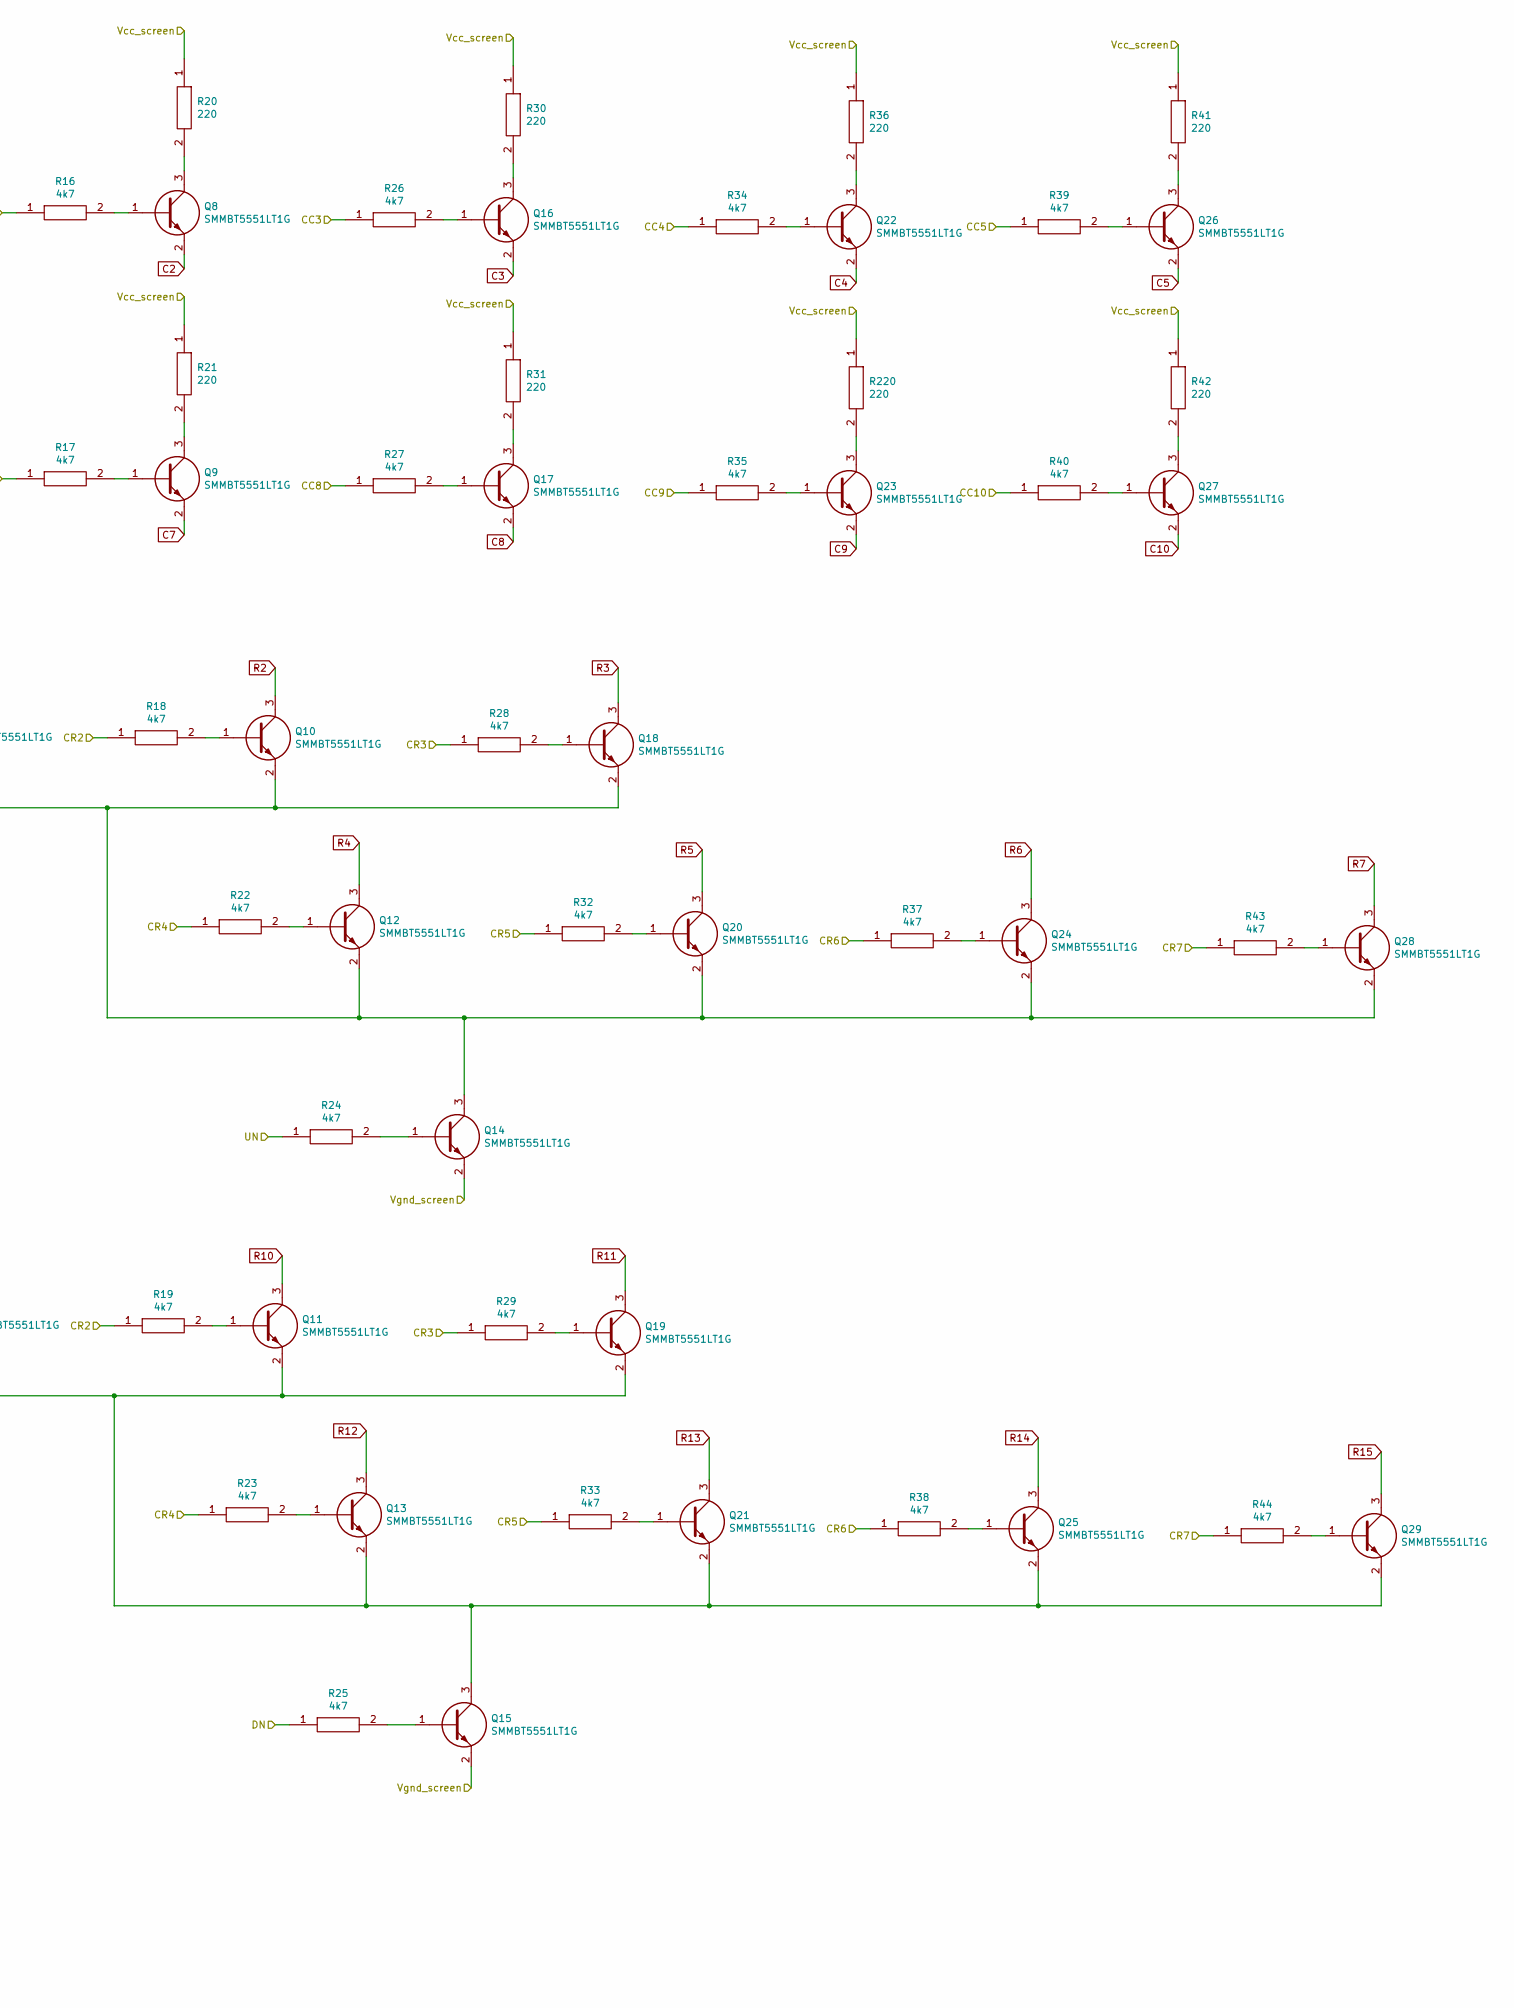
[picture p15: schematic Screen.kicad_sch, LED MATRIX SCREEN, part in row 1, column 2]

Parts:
LED1, LED2, LED3, LED4, LED5, LED6, LED7, LED8, LED9, LED10, LED11, LED12, LED13, LED14, LED15, LED16, LED17, LED18, LED19, LED20, LED21, LED22, LED23, LED24, LED25, LED26, LED27, LED28, LED29, LED30, LED31, LED32, LED33, LED34, LED35, LED36, LED37, LED38, LED39, LED40, LED41, LED42, LED43, LED44, LED45, LED46, LED47, LED48, LED49, LED50, LED51, LED52, LED53, LED54, LED55, LED56, LED57, LED58, LED59, LED60, LED61, LED62, LED63, LED64, LED65, LED66, LED67, LED68, LED69, LED70, LED71, LED72, LED73, LED74, LED75, LED76, LED77, LED78, LED79, LED80, LED81, LED82, LED83, LED84, LED85, LED86, LED87, LED88, LED89, LED90, LED91, LED92, LED93, LED94, LED95, LED96, LED97, LED98, LED99, LED100, LED101, LED102, LED103, LED104, LED105, LED106, LED107, LED108, LED109, LED110, LED111, LED112, LED113, LED114, LED115, LED116, LED117, LED118, LED119, LED120, LED121, LED122, LED123, LED124, LED125, LED126, LED127, LED128, LED129, LED130, LED131, LED132, LED133, LED134, LED135, LED136, LED137, LED138, LED139, LED140, LED141, LED142, LED143, LED144, LED145, LED146, LED147, LED148, LED149, LED150, LED151, LED152, LED153, LED154, LED155, LED156, LED157, LED158, LED159, LED160: LTST-C171GKT; LEDC2012X90N; Manufacturer_Part_Number LTST-C171GKT
Q2, Q3, Q4, Q5, Q6, Q7, Q8, Q9, Q10, Q11, Q12, Q13, Q14, Q15, Q16, Q17, Q18, Q19, Q20, Q21, Q22, Q23, Q24, Q25, Q26, Q27, Q28, Q29: SMMBT5551LT1G; SOT96P237X111-3N; Manufacturer_Part_Number SMMBT5551LT1G
R8, R9, R10, R11, R12, R13, R16, R17, R18, R19, R22, R23, R24, R25, R26, R27, R28, R29, R32, R33, R34, R35, R37, R38, R39, R40, R43, R44: 4k7; RESC2012X65N; Manufacturer_Part_Number KTR10EZPF4220
R14, R15, R20, R21, R30, R31, R36, R41, R42, R220: 220; RESC2012X65N; Manufacturer_Part_Number KTR10EZPF4220

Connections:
C1: LED1.2 (A), LED2.2 (A), LED3.2 (A), LED4.2 (A), LED5.2 (A), LED6.2 (A), LED7.2 (A), LED8.2 (A), LED9.2 (A), LED10.2 (A), LED11.2 (A), LED12.2 (A), LED13.2 (A), LED14.2 (A), LED15.2 (A), LED16.2 (A), Q4.2
C2: LED17.2 (A), LED18.2 (A), LED19.2 (A), LED20.2 (A), LED21.2 (A), LED22.2 (A), LED23.2 (A), LED24.2 (A), LED25.2 (A), LED26.2 (A), LED27.2 (A), LED28.2 (A), LED29.2 (A), LED30.2 (A), LED31.2 (A), LED32.2 (A), Q8.2
C3: LED33.2 (A), LED34.2 (A), LED35.2 (A), LED36.2 (A), LED37.2 (A), LED38.2 (A), LED39.2 (A), LED40.2 (A), LED41.2 (A), LED42.2 (A), LED43.2 (A), LED44.2 (A), LED45.2 (A), LED46.2 (A), LED47.2 (A), LED48.2 (A), Q16.2
C4: LED49.2 (A), LED50.2 (A), LED51.2 (A), LED52.2 (A), LED53.2 (A), LED54.2 (A), LED55.2 (A), LED56.2 (A), LED57.2 (A), LED58.2 (A), LED59.2 (A), LED60.2 (A), LED61.2 (A), LED62.2 (A), LED63.2 (A), LED64.2 (A), Q22.2
C5: LED65.2 (A), LED66.2 (A), LED67.2 (A), LED68.2 (A), LED69.2 (A), LED70.2 (A), LED71.2 (A), LED72.2 (A), LED73.2 (A), LED74.2 (A), LED75.2 (A), LED76.2 (A), LED77.2 (A), LED78.2 (A), LED79.2 (A), LED80.2 (A), Q26.2
C6: LED81.2 (A), LED82.2 (A), LED83.2 (A), LED84.2 (A), LED85.2 (A), LED86.2 (A), LED87.2 (A), LED88.2 (A), LED89.2 (A), LED90.2 (A), LED91.2 (A), LED92.2 (A), LED93.2 (A), LED94.2 (A), LED95.2 (A), LED96.2 (A), Q5.2
C7: LED97.2 (A), LED98.2 (A), LED99.2 (A), LED100.2 (A), LED101.2 (A), LED102.2 (A), LED103.2 (A), LED104.2 (A), LED105.2 (A), LED106.2 (A), LED107.2 (A), LED108.2 (A), LED109.2 (A), LED110.2 (A), LED111.2 (A), LED112.2 (A), Q9.2
C8: LED113.2 (A), LED114.2 (A), LED115.2 (A), LED116.2 (A), LED117.2 (A), LED118.2 (A), LED119.2 (A), LED120.2 (A), LED121.2 (A), LED122.2 (A), LED123.2 (A), LED124.2 (A), LED125.2 (A), LED126.2 (A), LED127.2 (A), LED128.2 (A), Q17.2
C9: LED129.2 (A), LED130.2 (A), LED131.2 (A), LED132.2 (A), LED133.2 (A), LED134.2 (A), LED135.2 (A), LED136.2 (A), LED137.2 (A), LED138.2 (A), LED139.2 (A), LED140.2 (A), LED141.2 (A), LED142.2 (A), LED143.2 (A), LED144.2 (A), Q23.2
C10: LED145.2 (A), LED146.2 (A), LED147.2 (A), LED148.2 (A), LED149.2 (A), LED150.2 (A), LED151.2 (A), LED152.2 (A), LED153.2 (A), LED154.2 (A), LED155.2 (A), LED156.2 (A), LED157.2 (A), LED158.2 (A), LED159.2 (A), LED160.2 (A), Q27.2
ICSPCLK: R37.1, R38.1; also elsewhere on the board
ICSPDA: R43.1, R44.1; also elsewhere on the board
unnamed: Q2.1, R8.2
unnamed: Q3.1, R9.2
unnamed: Q4.1, R10.2
unnamed: Q4.3, R14.2
unnamed: Q5.1, R11.2
unnamed: Q5.3, R15.2
unnamed: Q6.1, R12.2
unnamed: Q7.1, R13.2
unnamed: Q8.1, R16.2
unnamed: Q8.3, R20.2
unnamed: Q9.1, R17.2
unnamed: Q9.3, R21.2
unnamed: Q10.1, R18.2
unnamed: Q2.2, Q6.2, Q10.2, Q12.2, Q14.3, Q18.2, Q20.2, Q24.2, Q28.2
unnamed: Q11.1, R19.2
unnamed: Q3.2, Q7.2, Q11.2, Q13.2, Q15.3, Q19.2, Q21.2, Q25.2, Q29.2
unnamed: Q12.1, R22.2
unnamed: Q13.1, R23.2
unnamed: Q14.1, R24.2
unnamed: Q15.1, R25.2
unnamed: Q16.1, R26.2
unnamed: Q16.3, R30.2
unnamed: Q17.1, R27.2
unnamed: Q17.3, R31.2
unnamed: Q18.1, R28.2
unnamed: Q19.1, R29.2
unnamed: Q20.1, R32.2
unnamed: Q21.1, R33.2
unnamed: Q22.1, R34.2
unnamed: Q22.3, R36.2
unnamed: Q23.1, R35.2
unnamed: Q23.3, R220.2
unnamed: Q24.1, R37.2
unnamed: Q25.1, R38.2
unnamed: Q26.1, R39.2
unnamed: Q26.3, R41.2
unnamed: Q27.1, R40.2
unnamed: Q27.3, R42.2
unnamed: Q28.1, R43.2
unnamed: Q29.1, R44.2
P_CC1: R10.1; also elsewhere on the board
P_CC2: R16.1; also elsewhere on the board
P_CC3: R26.1; also elsewhere on the board
P_CC4: R34.1; also elsewhere on the board
P_CC5: R39.1; also elsewhere on the board
P_CC6: R11.1; also elsewhere on the board
P_CC7: R17.1; also elsewhere on the board
P_CC8: R27.1; also elsewhere on the board
P_CC9: R35.1; also elsewhere on the board
P_CC10: R40.1; also elsewhere on the board
P_CR0: R8.1, R9.1; also elsewhere on the board
P_CR1: R12.1, R13.1; also elsewhere on the board
P_CR2: R18.1, R19.1; also elsewhere on the board
P_CR3: R28.1, R29.1; also elsewhere on the board
P_CR4: R22.1, R23.1; also elsewhere on the board
P_CR5: R32.1, R33.1; also elsewhere on the board
P_DN: R25.1; also elsewhere on the board
P_UN: R24.1; also elsewhere on the board
R0: LED1.1 (K), LED17.1 (K), LED33.1 (K), LED49.1 (K), LED65.1 (K), LED81.1 (K), LED97.1 (K), LED113.1 (K), LED129.1 (K), LED145.1 (K), Q2.3
R1: LED2.1 (K), LED18.1 (K), LED34.1 (K), LED50.1 (K), LED66.1 (K), LED82.1 (K), LED98.1 (K), LED114.1 (K), LED130.1 (K), LED146.1 (K), Q6.3
R2: LED3.1 (K), LED19.1 (K), LED35.1 (K), LED51.1 (K), LED67.1 (K), LED83.1 (K), LED99.1 (K), LED115.1 (K), LED131.1 (K), LED147.1 (K), Q10.3
R3: LED4.1 (K), LED20.1 (K), LED36.1 (K), LED52.1 (K), LED68.1 (K), LED84.1 (K), LED100.1 (K), LED116.1 (K), LED132.1 (K), LED148.1 (K), Q18.3
R4: LED5.1 (K), LED21.1 (K), LED37.1 (K), LED53.1 (K), LED69.1 (K), LED85.1 (K), LED101.1 (K), LED117.1 (K), LED133.1 (K), LED149.1 (K), Q12.3
R5: LED6.1 (K), LED22.1 (K), LED38.1 (K), LED54.1 (K), LED70.1 (K), LED86.1 (K), LED102.1 (K), LED118.1 (K), LED134.1 (K), LED150.1 (K), Q20.3
R6: LED7.1 (K), LED23.1 (K), LED39.1 (K), LED55.1 (K), LED71.1 (K), LED87.1 (K), LED103.1 (K), LED119.1 (K), LED135.1 (K), LED151.1 (K), Q24.3
R7: LED8.1 (K), LED24.1 (K), LED40.1 (K), LED56.1 (K), LED72.1 (K), LED88.1 (K), LED104.1 (K), LED120.1 (K), LED136.1 (K), LED152.1 (K), Q28.3
R8: LED9.1 (K), LED25.1 (K), LED41.1 (K), LED57.1 (K), LED73.1 (K), LED89.1 (K), LED105.1 (K), LED121.1 (K), LED137.1 (K), LED153.1 (K), Q3.3
R9: LED10.1 (K), LED26.1 (K), LED42.1 (K), LED58.1 (K), LED74.1 (K), LED90.1 (K), LED106.1 (K), LED122.1 (K), LED138.1 (K), LED154.1 (K), Q7.3
R10: LED11.1 (K), LED27.1 (K), LED43.1 (K), LED59.1 (K), LED75.1 (K), LED91.1 (K), LED107.1 (K), LED123.1 (K), LED139.1 (K), LED155.1 (K), Q11.3
R11: LED12.1 (K), LED28.1 (K), LED44.1 (K), LED60.1 (K), LED76.1 (K), LED92.1 (K), LED108.1 (K), LED124.1 (K), LED140.1 (K), LED156.1 (K), Q19.3
R12: LED13.1 (K), LED29.1 (K), LED45.1 (K), LED61.1 (K), LED77.1 (K), LED93.1 (K), LED109.1 (K), LED125.1 (K), LED141.1 (K), LED157.1 (K), Q13.3
R13: LED14.1 (K), LED30.1 (K), LED46.1 (K), LED62.1 (K), LED78.1 (K), LED94.1 (K), LED110.1 (K), LED126.1 (K), LED142.1 (K), LED158.1 (K), Q21.3
R14: LED15.1 (K), LED31.1 (K), LED47.1 (K), LED63.1 (K), LED79.1 (K), LED95.1 (K), LED111.1 (K), LED127.1 (K), LED143.1 (K), LED159.1 (K), Q25.3
R15: LED16.1 (K), LED32.1 (K), LED48.1 (K), LED64.1 (K), LED80.1 (K), LED96.1 (K), LED112.1 (K), LED128.1 (K), LED144.1 (K), LED160.1 (K), Q29.3
Vcc_main: R14.1, R15.1, R20.1, R21.1, R30.1, R31.1, R36.1, R41.1, R42.1, R220.1; also elsewhere on the board
Vgnd_main: Q14.2, Q15.2; also elsewhere on the board

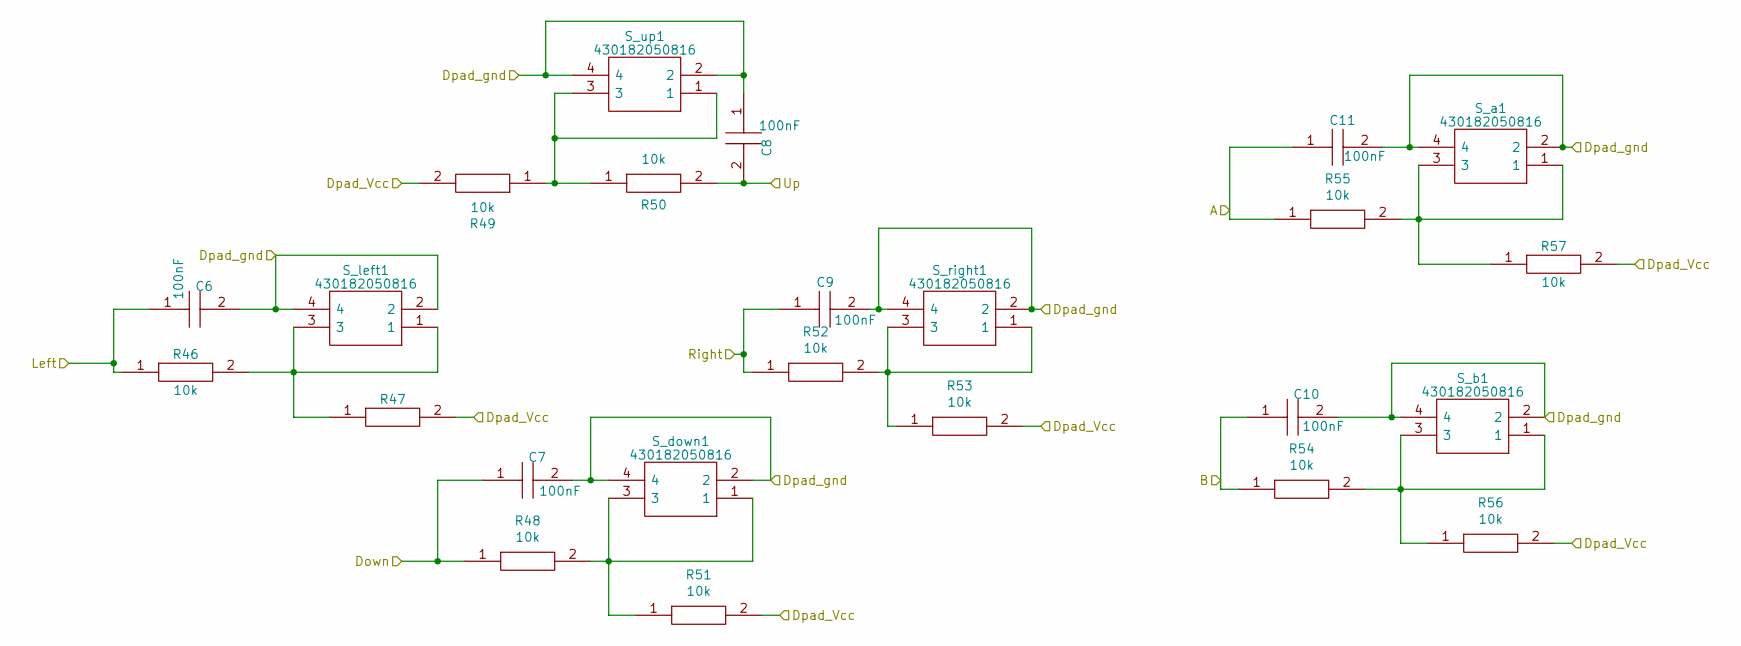
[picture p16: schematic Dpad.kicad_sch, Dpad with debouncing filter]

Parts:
C6, C7, C8, C9, C10, C11: 100nF; CAPC2012X140N; Manufacturer_Part_Number GCG21BR71H154KA01K
R46, R48, R49, R52, R54, R55: 10k; RESC2012X75N; Manufacturer_Part_Number KTR10EZPF4220
R47, R50, R51, R53, R56, R57: 10k; RESC2012X65N; Manufacturer_Part_Number KTR10EZPF4220
S_a1: 430182050816; 430182070816; Mouser Part Number 710-430182050816
S_b1: 430182050816; 430182070816; Mouser Part Number 710-430182050816
S_down1: 430182050816; 430182070816; Mouser Part Number 710-430182050816
S_left1: 430182050816; 430182070816; Mouser Part Number 710-430182050816
S_right1: 430182050816; 430182070816; Mouser Part Number 710-430182050816
S_up1: 430182050816; 430182070816; Mouser Part Number 710-430182050816

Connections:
unnamed: R46.2, R47.1, S_left1.1, S_left1.3
unnamed: R48.2, R51.1, S_down1.1, S_down1.3
unnamed: R49.1, R50.1, S_up1.1, S_up1.3
unnamed: R52.2, R53.1, S_right1.1, S_right1.3
unnamed: R54.2, R56.1, S_b1.1, S_b1.3
unnamed: R55.2, R57.1, S_a1.1, S_a1.3
S_a: C11.1, R55.1; also elsewhere on the board
S_b: C10.1, R54.1; also elsewhere on the board
S_down: C7.1, R48.1; also elsewhere on the board
S_left: C6.1, R46.1; also elsewhere on the board
S_right: C9.1, R52.1; also elsewhere on the board
S_up: C8.2, R50.2; also elsewhere on the board
Vcc_main: R47.2, R49.2, R51.2, R53.2, R56.2, R57.2; also elsewhere on the board
Vgnd_main: C6.2, C7.2, C8.1, C9.2, C10.2, C11.2, S_a1.2, S_a1.4, S_b1.2, S_b1.4, S_down1.2, S_down1.4, S_left1.2, S_left1.4, S_right1.2, S_right1.4, S_up1.2, S_up1.4; also elsewhere on the board

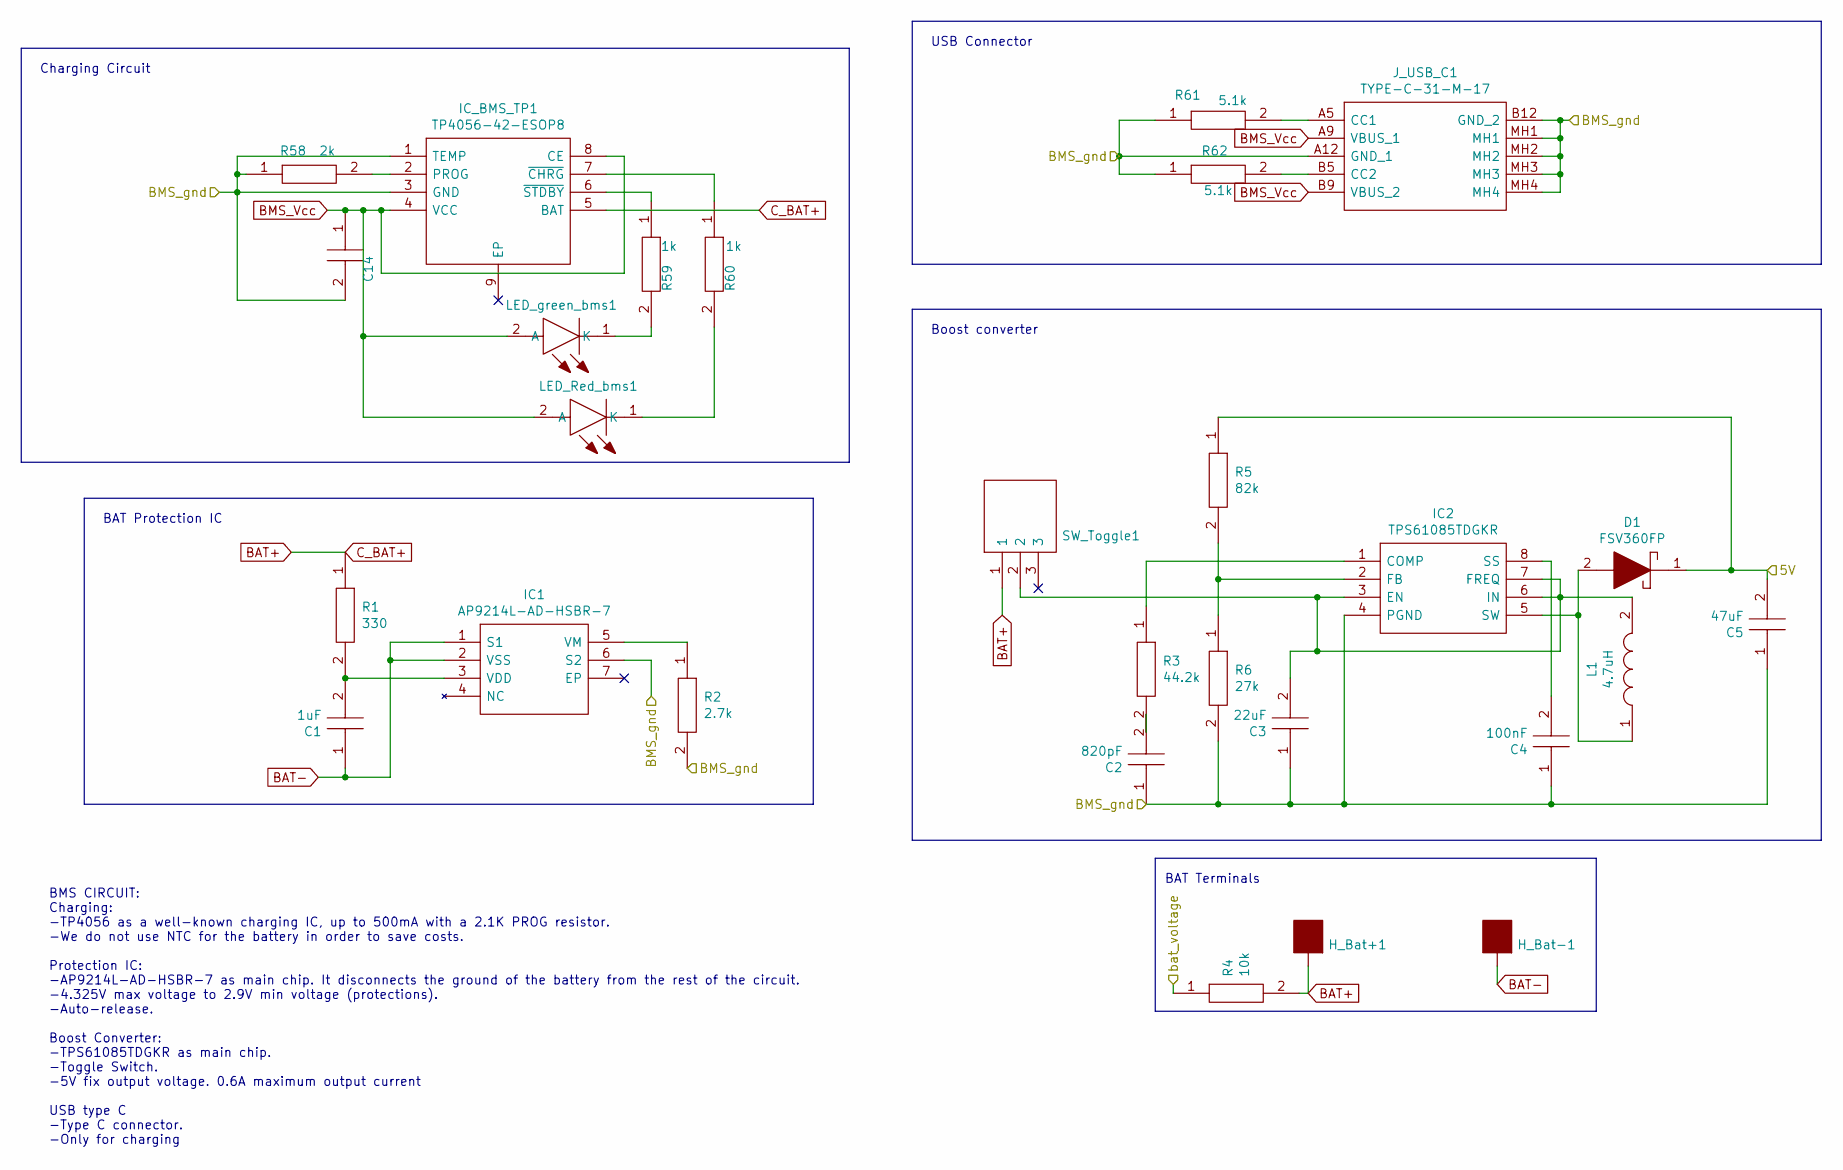
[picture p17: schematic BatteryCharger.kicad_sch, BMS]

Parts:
C1: 1uF; CAPC2012X140N; Manufacturer_Part_Number C0805C475M8RACTU
C2: 820pF; CAPC2012X140N; Manufacturer_Part_Number C0805C475M8RACTU
C3: 22uF; CAPC2012X140N; Manufacturer_Part_Number C0805C475M8RACTU
C4: 100nF; CAPC2012X140N; Manufacturer_Part_Number C0805C475M8RACTU
C5: 47uF; CAPC2012X140N; Manufacturer_Part_Number C0805C475M8RACTU
C14: 10uF; CAPC2012X145N; Manufacturer_Part_Number GCG21BR71H154KA01K
D1: FSV360FP; SS12FP; Mouser Part Number 512-FSV360FP
H_Bat+1: MountingHole_Pad-User_library-SamacSys_Parts; Mounting-Pad
H_Bat-1: MountingHole_Pad-User_library-SamacSys_Parts; Mounting-Pad
IC1: AP9214L-AD-HSBR-7; AP9214LANHSBR7; Mouser Part Number 621-AP9214L-AN-HSBR7
IC2: TPS61085TDGKR; SOP65P490X110-8N; Mouser Part Number 595-TPS61085TDGKR
IC_BMS_TP1: TP4056-42-ESOP8; SOIC127P600X175-9N; Manufacturer_Part_Number TP4056-42-ESOP8
J_USB_C1: TYPE-C-31-M-17; TYPEC31M17; Manufacturer_Part_Number TYPE-C-31-M-17
L1: 4.7uH; SRN6045_1; Mouser Part Number 652-SRN6045-4R7Y
LED_Red_bms1: LTST-C171GKT; LEDC2012X90N; Manufacturer_Part_Number LTST-C171GKT
LED_green_bms1: LTST-C171GKT; LEDC2012X90N; Manufacturer_Part_Number LTST-C171GKT
R1: 330; RESC2012X75N; Manufacturer_Part_Number ERJP6WF1303V
R2: 2.7k; RESC2012X75N; Manufacturer_Part_Number ERJP6WF1303V
R3: 44.2k; RESC2012X75N; Manufacturer_Part_Number ERJP6WF1303V
R4: 10k; RESC2012X75N; Manufacturer_Part_Number ERJP6WF1303V
R5: 82k; RESC2012X75N; Manufacturer_Part_Number ERJP6WF1303V
R6: 27k; RESC2012X75N; Manufacturer_Part_Number ERJP6WF1303V
R58: 2k; RESC2012X65N; Manufacturer_Part_Number KTR10EZPF4220
R59, R60: 1k; RESC2012X65N; Manufacturer_Part_Number KTR10EZPF4220
R61, R62: 5.1k; RESC2012X65N; Manufacturer_Part_Number KTR10EZPF4220
SW_Toggle1: K3-1260D-L1; K31260DL1; Manufacturer_Part_Number K3-1260D-L1

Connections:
BAT+: H_Bat+1.1, IC_BMS_TP1.5 (BAT), R1.1, R4.2, SW_Toggle1.1
BAT-: C1.1, H_Bat-1.1, IC1.1 (S1), IC1.2 (VSS)
BMS_Vcc: C14.1, IC_BMS_TP1.4 (VCC), IC_BMS_TP1.8 (CE), J_USB_C1.A9 (VBUS_1), J_USB_C1.B9 (VBUS_2), LED_Red_bms1.2 (A), LED_green_bms1.2 (A)
unnamed: C2.2, R3.2
unnamed: C1.2, IC1.3 (VDD), R1.2
unnamed: IC1.5 (VM), R2.1
unnamed: IC2.1 (COMP), R3.1
unnamed: C3.2, IC2.3 (EN), IC2.6 (IN), IC2.7 (FREQ), L1.2, SW_Toggle1.2
unnamed: IC2.2 (FB), R5.2, R6.1
unnamed: C4.2, IC2.8 (SS)
unnamed: D1.2, IC2.5 (SW), L1.1
unnamed: IC_BMS_TP1.2 (PROG), R58.2
unnamed: IC_BMS_TP1.7 (~CHRG), R60.1
unnamed: IC_BMS_TP1.6 (~STDBY), R59.1
unnamed: J_USB_C1.A5 (CC1), R61.2
unnamed: J_USB_C1.B5 (CC2), R62.2
unnamed: LED_Red_bms1.1 (K), R60.2
unnamed: LED_green_bms1.1 (K), R59.2
Vcc_main: C5.2, D1.1, R5.1; also elsewhere on the board
Vdc_battery: R4.1; also elsewhere on the board
Vgnd_main: C2.1, C3.1, C4.1, C5.1, C14.2, IC1.6 (S2), IC2.4 (PGND), IC_BMS_TP1.1 (TEMP), IC_BMS_TP1.3 (GND), J_USB_C1.A12 (GND_1), J_USB_C1.B12 (GND_2), J_USB_C1.MH1, J_USB_C1.MH2, J_USB_C1.MH3, J_USB_C1.MH4, R2.2, R6.2, R58.1, R61.1, R62.1; also elsewhere on the board

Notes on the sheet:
Boost converter
BMS CIRCUIT: Charging: -TP4056 as a well-known charging IC, up to 500mA with a 2.1K PROG resistor. -We do not use NTC for the battery in order to save costs. Protection IC: -AP9214L-AD-HSBR-7 as main chip. It disconnects the ground of the battery from the rest of the circuit. -4.325V max voltage to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
BAT Protection IC
USB Connector
BAT Terminals
Charging Circuit

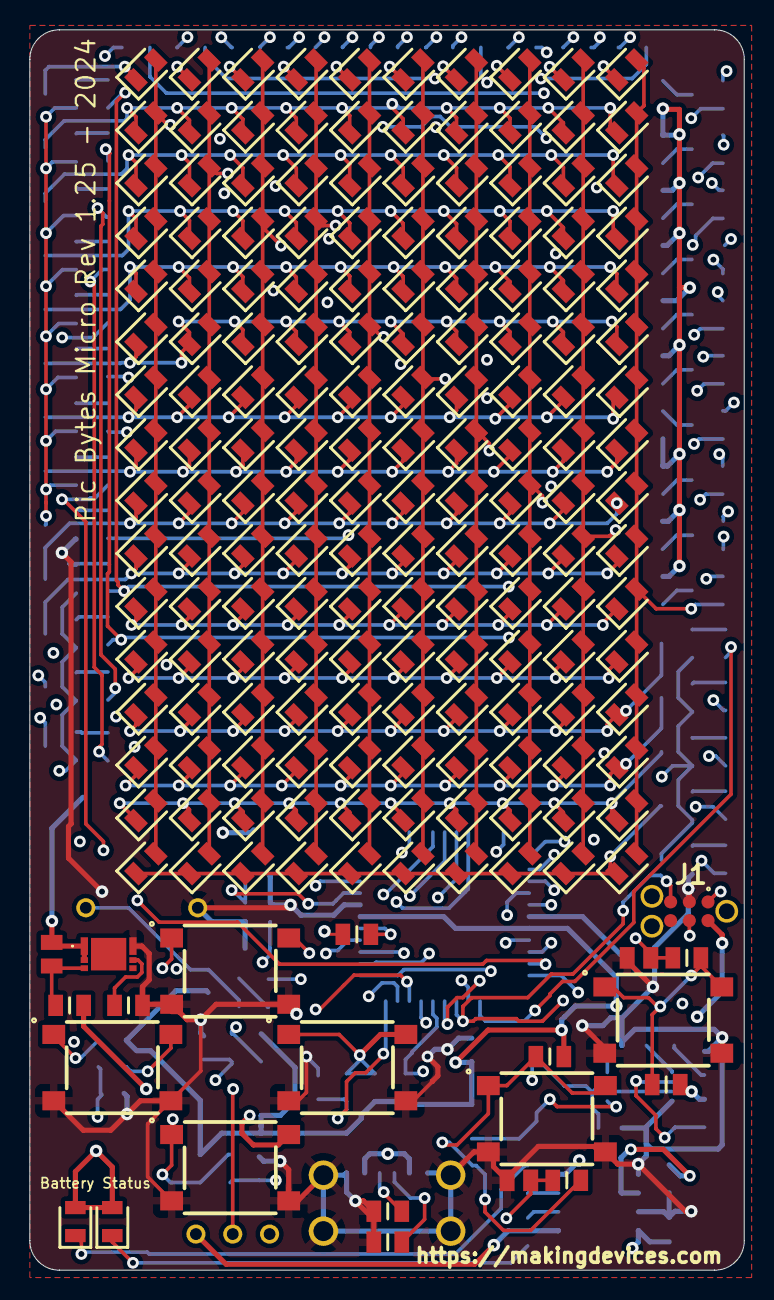
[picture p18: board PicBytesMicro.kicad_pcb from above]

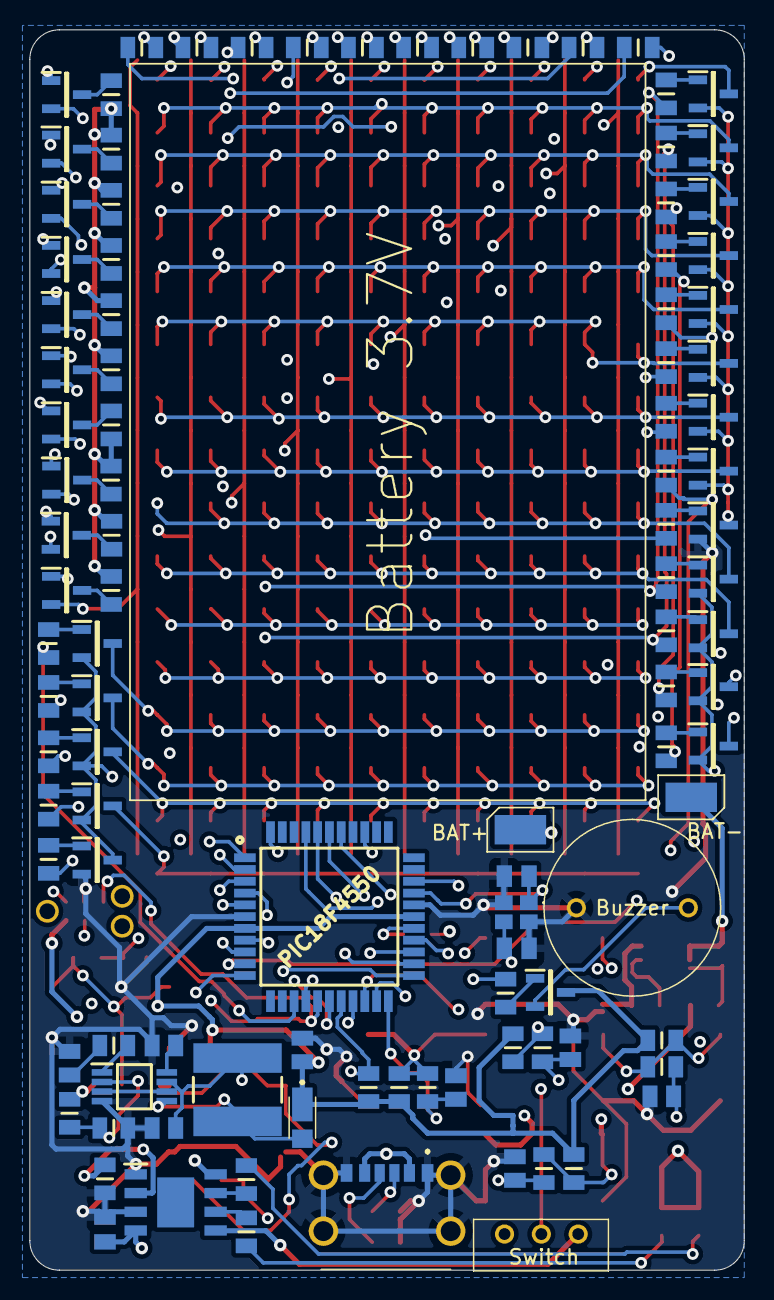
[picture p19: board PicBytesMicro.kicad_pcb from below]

Board: 4 copper layers, 48.5 x 84.2 mm, 287 parts (105 on the bottom side), 125 nets.

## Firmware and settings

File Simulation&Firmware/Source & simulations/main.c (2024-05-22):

/*	Making Devices 2024
	https://makingdevices.com
	Rubén García Segovia
	  Pic Bytes Micro
*/
// CONFIG1H
#pragma config FOSC = HSPLL_HS // Oscillator Selection bits (HS oscillator, PLL enabled (HSPLL))
#pragma config FCMEN = OFF // Fail-Safe Clock Monitor Enable bit (Fail-Safe Clock Monitor disabled)
#pragma config IESO = OFF // Internal/External Oscillator Switchover bit (Oscillator Switchover mode disabled)
#pragma config LVP = OFF //Disable low voltage programmer so we can use RB5.

//Declarations of big chunks of data


int arkanoid_game_speed = 800;
int snake_game_speed = 250;
int tetris_game_speed = 200;
char buzzer_enable = 1; //1 = enabled // 0 = disabled
char splash_enabled = 0; //1 = enabled // 0 = disabled
char voltage_detector = 1; //1 = enabled // 0 = disabled (for old HW)
char game=0;
unsigned int sleep_time = 23000; //Time before deep sleep
unsigned int deep_sleep = 0;
char sleep_counter_multiplier = 0;

#include "graphics.h"
#include "tetris_data.h"

#include <p18f4550.h>
#include <delays.h>
#include "EEPROM.h"
#include "core.h"
#include "snake.h"
#include "arkanoid_lvl.h"
#include "arkanoid.h"
#include "tetris.h"

/*
Screen: 10x16
*/

void _low_isr (void);
void _high_isr (void);

#pragma code low_vector=0x18 //Low interrupt priority starts at 0x18
void low_interrupt(void)
{
_asm goto _low_isr _endasm
}

#pragma code high_vector=0x08 //High interrupt priority starts at 0x08
void high_interrupt(void)
{
_asm goto _high_isr _endasm
}
#pragma code


#pragma interrupt _low_isr
char state = 0;

void _low_isr (void)
{
//PIR1bits.TMR1IF
//INTCONbits.TMR0IF
if(PIR1bits.TMR1IF) //Timer0 interrupt
{
	if(++sleep_counter_multiplier>2 && deep_sleep <= sleep_time){
		deep_sleep++;
		sleep_counter_multiplier = 0;
	}
	if(buttonmap!=0)deep_sleep=0;
	if(buzer_beep_timer>0 && buzzer_enable==1){
		buzer_beep_timer -= 2;
		LATCbits.LATC2 = 1;
	} else {
		LATCbits.LATC2 = 0;
	}
	if(ingame==1) clean_buttons();
	update_buttons();
	print_screen();
	if(game_selection==0)check_movement();
	if(game_selection==2)check_movement_arkanoid();
	if(game_selection==1)check_movement_tetris();
    TMR1H = 0xE8;
    TMR1L = 0x90;
	PIR1bits.TMR1IF = 0; // reset overflow bit
}
}

#pragma interrupt _high_isr
void _high_isr (void)
{
if(INTCONbits.INT0IF) //Reset 
{
	INTCONbits.INT0IF = 0;
}
}


/* ****************** MAIN ****************** */
float bat_voltage;
int ADC_digit;
void main(void)
{	
	if(voltage_detector ==1){
		ADC_Init();
		ADC_digit=ADC_Read();
		bat_voltage= ADC_digit*((float)5.0/(float)1023);
	} else bat_voltage = 4;
	if(readEE(202) == 0xFF) initiate_EEPROM();
	splash_enabled = readEE(202);
	Delay10KTCYx(5);
	buzzer_enable = readEE(203);
	Delay10KTCYx(5);
	splash_init();
	if(bat_voltage<3.25) low_batt_alert();
	menu();
	clean_screen();
	if(game_selection==0) snake_sel_init();
	if(game_selection==2) arkanoid_sel_init();
	if(game_selection==1) tetris_sel_init();
	while(game_selection==0){
		delay_timer1(snake_game_speed);
		food_snake();
		move_snake();
	}
	while(game_selection==2){
		delay_timer1(arkanoid_game_speed);
		move_ball();
		//Wait until the game is done
	}
	while(game_selection==1){
		delay_timer1(tetris_game_speed);
		move_tetrominoe();
	}
	Sleep();
}

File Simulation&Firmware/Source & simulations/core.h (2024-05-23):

/*	Making Devices 2020
	https://makingdevices.com
	Rubén García Segovia
	Pic Bytes Micro
*/

#ifndef __Core
#define __Core

char screenmap_index = 0;

char screenmap[24] = { 
     0b00000000,
     0b00000000,
     0b00000000,
     0b00000000,
     0b00000000,
     0b00000000,
     0b00000000,
     0b00000000,
     0b00000000,
     0b00000000,
     0b00000000,
     0b00000000,
     0b00000000,
     0b00000000,
     0b00000000,
     0b00000000,
     0b00000000,
     0b00000000,
     0b00000000,
     0b00000000,
     0b00000000,
     0b00000000,
     0b00000000,
     0b00000000,
 };

#pragma idata my_memory_section_2
char game_ram[70]={ 
     0b00000000,
     0b00000000,
     0b00000000,
     0b00000000,
     0b00000000,     
	 0b00000000,
     0b00000000,
     0b00000000,
     0b00000000,
     0b00000000,
     0b00000000,
     0b00000000,
     0b00000000,
     0b00000000,
     0b00000000,     
	 0b00000000,
     0b00000000,
     0b00000000,
     0b00000000,
     0b00000000,
     0b00000000,
     0b00000000,
     0b00000000,
     0b00000000,
     0b00000000,     
	 0b00000000,
     0b00000000,
     0b00000000,
     0b00000000,
     0b00000000,
     0b00000000,
     0b00000000,
     0b00000000,
     0b00000000,
     0b00000000,     
	 0b00000000,
     0b00000000,
     0b00000000,
     0b00000000,
     0b00000000,
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
 };
#pragma idata my_memory_section_2

char buttonmap = 0b00000000;	//Player one

/*
0b12345678
1: Up arrow
2: Down arrow
3: Left arrow
4: Rigth arrow
5: S_b
6: S_a
7: 
8:
*/

int ingame = 0;			// We should start at 0
int game_selection = 9;    //We should start at 9
float buzer_beep_timer = 0;
int speed_menu = 220; //1 = without movement // 0 = with movement
char timer1_counter = 2; //Around 2ms

void ADC_Init()
{    	
	TRISEbits.TRISE2 = 1;  /* Set RE2 as input port */
    //ADCON1 = 0x0E;	/* Ref vtg is VDD and Configure pin as analog pin */
    ADCON1 = 0b00000111; //Vss and Vdd as reference. AN7 ANALOG
	ADCON2 = 0x92;	/* Right Justified, 4Tad and Fosc/32. */
    ADRESH=0;		/* Flush ADC output Register */
    ADRESL=0;   
} 

int ADC_Read(void)
{
    int digital;

    /* Channel 7 is selected  */
    ADCON0bits.CHS = 7;
    ADCON0bits.ADON = 1;
    ADCON0bits.GO = 1;	/*Enable ADC and start conversion*/
	
    /* Wait for End of conversion i.e. Go/done'=0 conversion completed */
    while(ADCON0bits.GO==1);

    digital = (ADRESH*256) | (ADRESL);	/*Combine 8-bit LSB and 2-bit MSB*/
    return(digital);
}

void write_button(char buttonx){
	char new_value= 0b10000000;
	buttonx--;
	new_value = new_value >> buttonx;
	buttonmap = buttonmap|new_value;
}

char read_button(char buttonx){
	char answer = 0b00000000;
	answer = buttonmap >> (8-buttonx);
	answer = answer&0b00000001;
	return answer;
}

void clean_buttons(void){
	buttonmap=0;
}
char buzzer_beep(float time){
	if(buzzer_enable==1){
		buzer_beep_timer=time;
		return 0;
	}
	return 1;
}
void update_buttons(void){
	if(PORTAbits.RA0==0) write_button(1); // Up
	if(PORTAbits.RA1==0) write_button(2); // Down
	if(PORTAbits.RA2==0) write_button(3); // Left
	if(PORTAbits.RA3==0) write_button(4); // Right
	if(PORTAbits.RA4==0) write_button(5); // B
	if(PORTAbits.RA5==0) write_button(6); // A

}

void print_screen(void){
	char row_controlled;
	row_controlled = screenmap_index;
	LATE = 0b00000000;
	
	if(row_controlled>7){
		row_controlled-=8;
		LATC = ((screenmap[row_controlled+16]&0b00110000)<<2);
		
	} else {
		LATC = (screenmap[row_controlled+16]&0b11000000);
	}
	LATB = 0b00000001 << row_controlled;
	LATD = screenmap[screenmap_index];

	if(screenmap_index>7){
		LATE = 0b00000001;
	} else {
		LATE = 0b00000010;
	}
	screenmap_index++;
	if(screenmap_index==16)screenmap_index=0;
}

char read_screen(char x, char y){
	char answer = 0b00000000;
	char index = 0;
	x--;
	y--;
	if(x==8 || x == 9){
		if(y>=8 && y<16){
			y-=8;
			x+=2;
		}
		x -=8;
		index = 16;
	}
	x = 7 - x;
	answer = screenmap[y+index] >> x;
	answer = answer&0b00000001;
	return answer;
}


void write_screen(char x, char y, char value){
	if((x>0 && x<11)&&(y>0 && y<17)) {
		char new_value= 0b10000000;
		char index = 0;
		x--;
		y--;
	
		if(x==8 || x == 9){
			if(y>=8){
				new_value= 0b00100000;
				y-=8;
			}
			x -=8;
			index = 16;
		}
		value = value&0b00000001;
		new_value = new_value >> x;
		if(value==1){
			screenmap[y+index] = screenmap[y+index]|new_value;
		} else {
			screenmap[y+index] = screenmap[y+index]&~new_value;
		}
	}
}

void clean_screen(void){
char i, j;
	for(i=1;i<17;i++){
		for(j=1;j<11;j++){
			write_screen(j,i,0);
		}
	}
}

void print_sprite(char x, char y, char *sprite){
	char i = 0;
	for (i=0; i<5; i++)
	{
    	if(((sprite[0]>>(7-i))&1)==1)write_screen(x+i,y,(sprite[0]>>(7-i))&1);
		if(((sprite[1]>>(7-i))&1)==1)write_screen(x+i,y+1,(sprite[1]>>(7-i))&1);
		if(((sprite[2]>>(7-i))&1)==1)write_screen(x+i,y+2,(sprite[2]>>(7-i))&1);
		if(((sprite[3]>>(7-i))&1)==1)write_screen(x+i,y+3,(sprite[3]>>(7-i))&1);
		if(((sprite[4]>>(7-i))&1)==1)write_screen(x+i,y+4,(sprite[4]>>(7-i))&1);
	}
}

void remove_sprite(char x, char y, char *sprite){
	char i = 0;
	for (i=0; i<5; i++)
	{
    	if(((sprite[0]>>(7-i))&1)==1) write_screen(x+i,y,0);
		if(((sprite[1]>>(7-i))&1)==1) write_screen(x+i,y+1,0);
		if(((sprite[2]>>(7-i))&1)==1) write_screen(x+i,y+2,0);
		if(((sprite[3]>>(7-i))&1)==1) write_screen(x+i,y+3,0);
		if(((sprite[4]>>(7-i))&1)==1) write_screen(x+i,y+4,0);
	}
}

void timer1_start(void){

  T1CON	 = 0x00;
  TMR1H	 = 0xE2;  //Every 2.5ms
  TMR1L	 = 0xB4;
  PIE1bits.TMR1IE = 1;
  INTCON	 = 0xC0;
  RCONbits.IPEN       = 1;    //Enable Interrupt Priorities
  INTCONbits.GIEL     = 1;    //Enable Low Priority Interrupt
  IPR1bits.TMR1IP = 0; //TIMER 1 to low priority
  PIR1bits.TMR1IF = 0;  // T1 int flag bit cleared before starting
  T1CONbits.TMR1ON = 1;   // timer1 START

}

void delay_timer1(int time){  //let's wait "time" ms.
	int ms_counter = 0;
	char did_i_sleep = 0;
	while(ms_counter<time){
		ms_counter = ms_counter + timer1_counter;
		Sleep();
		if(deep_sleep>sleep_time){
			did_i_sleep = 1;
			ms_counter = 0;
			clean_screen();
		}
		if(game_selection > 3 && did_i_sleep == 1 && deep_sleep<=sleep_time) {
			print_sprite(9,10,letter_right);
			print_sprite(1,10,letter_left); 
		}
	}
}
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

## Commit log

2023-06-01 Moving to next version V1.0
    [BatteryCharger.kicad_sch, BatteryCharger.sch, Dpad.kicad_sch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]
2024-01-03 New V1.2 Hardware Release
    [BatteryCharger.kicad_sch, BatteryCharger.sch, Dpad.kicad_sch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]
2024-03-24 V1.25 FW release
    [BatteryCharger.kicad_sch, BatteryCharger.sch, Dpad.kicad_sch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]
2024-03-24 New HW v1.25 release
    [BatteryCharger.kicad_sch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]
2024-05-21 New v1.25. Some rescue libs were created as I updated into Kicad 8 with a clean install.
2024-06-04 Finished v1.25 version
    [Schematic_digital.DSN, mcc18 pragma config.txt]
2024-06-13 Bill Of Materials
    [BatteryCharger.kicad_sch, Dpad.kicad_sch, PicBytesMicro.kicad_pcb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]
